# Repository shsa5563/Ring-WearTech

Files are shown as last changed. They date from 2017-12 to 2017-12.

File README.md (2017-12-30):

# Ring-WearTech
A research project on wearable technology

Requirements to implement this project:

    Hardware: 
    1. EFR32BG13 - starter kit, BMA280, Android Phone.
    
    Software 
    1. Simplicity Studio 4, Android Studio
    
    Steps: 
    1. Import the Firmware from this project to the Simplicity Studio 4
    2. Connect EFR32BG13 through USB and start Debugging/Execute
    3. Use two different instances of the Android Studio and import BLE and DTW apps, and execute them 
       (With new version you dont have to generate any signed apks)
    4. Open the DTW app and the BLE app. 
    5. The BLE advertisements will be visible in the BLE app, select it.
    6. Double tap on the sensor (BMA280) - the acknowledgment of the double tap is displayed on the BLE app.
    7. The user can start the gestures/commands/notes and it will be automatically transferred to the DTW app. 
    8. The DTW app provides visual graphs of realtime-data received, 
       to train with a particular command/notes/gesture - switch the button to the traning mode and hold-down the touch. and relese the touch once you are done with the gesture. 
    9. To recognise the gesture/command/notes, switch the button to the recognition mode and hold-down the touch to record the gesture and release once done. 
    10. If it is a match, it will be displayed on the app.
   
If eager to build the entire project ground up, 

    1. The schematics and the Layout desins are given in the "Altium-Schematics_Layout" folder.
    2. The components to order are given in the Excel sheet in same folder. 
    3. Run a free DFM check, and Submit the Gerber files to PCBWay 

The workinng prototype is uploaded on youtube,

   1. Ring-WearTech: https://www.youtube.com/watch?v=jb6WAhV-7PE
   2. BLE MESH: https://www.youtube.com/watch?v=EVaqNhNOGpU

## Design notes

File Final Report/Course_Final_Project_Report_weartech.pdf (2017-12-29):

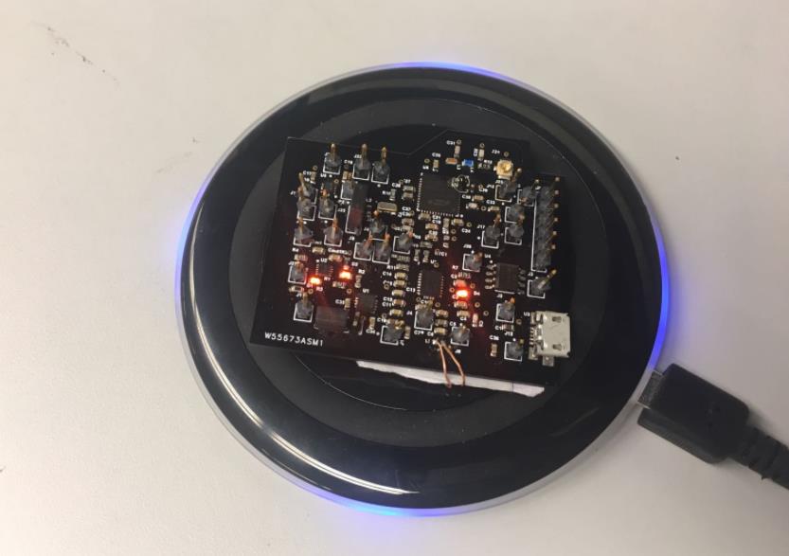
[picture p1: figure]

WearTech Project Report

LOW POWER EMBEDDED DESIGN
FINAL PROJECT REPORT

Team Name: WearTech

Team Mates:

Sanjana Kalyanappagol | Shekhar Satyanarayana
saka2821@colorado.edu | shsa5563@colorado.edu

Overview of the Project
A wearable ring/cap which is used to take short notes and control other devices through the movements of the user. The data is further sent to the application and trained using a Machine learning algorithm. The movements of the user are monitored using an accelerometer and it is also controlled using the tap sense of the accelerometer. The device is a prototype of a smart wearable technology which also obtains the ambient temperature and relays it to the application to display the ambient temperature.

What is the problem that this project is attempting to solve? How is this project going to solve this problem?

A wearable ring/cap which is used to take short notes and control other devices through the movements defined in the Mobile App.
With the advent of technology, it is bane to open your mobile/laptop/book to take a note of something important that strikes you all of a sudden or take a phone number of someone you meet unexpectedly. Say you are in a harsh environment, what if you had a wearable device with you all the time as a look-out for such situations.
In the Corporate world, say you are in a meeting and you need to take notes, rather than using notes/pens and disturbing others you can easily take notes of all the important points you need. Say in an unanticipated meeting, wouldn't you feel more secure, safe and confident with our device always at help.
In the field of Software Development & maintenance, one can face a lot of issues/bugs to be fixed within due dates. And with that constantly in mind, Most of us get solutions to the same when we are involved in our day-to-day activities such as driving, eating, talking with a friend, etc. Hence we would end up looking for a pen & paper, if not we would waste time memorizing the solution we had just found unless we have this device around which can keep a record of every thought that you want to be saved at any point of time.
Now with the buzz of IoT we have seen a lot of devices which could communicate with our home appliances. We provide a solution with the new Bluetooth Mesh Network to control other home appliances in addition to the Ring/Cap a single device which acts as a note taker.

The end-applications to such a device is enormous, it can be used to define the movement of a wheelchair, or used by old people/patients to communicate.

Use case described

Use Case Model to charge energy storage device:

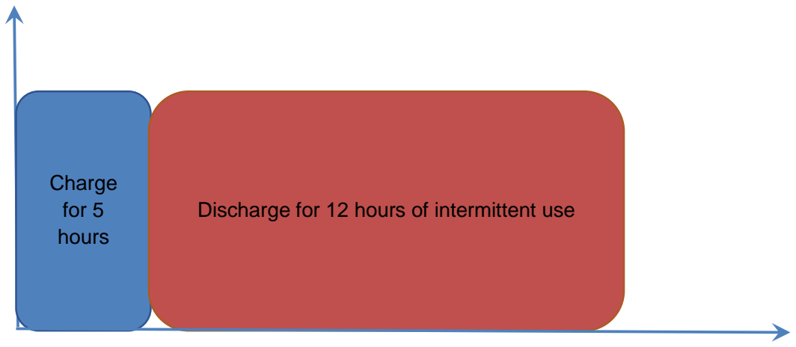
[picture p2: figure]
Charge for 5 hours

5hrs | 12hrs | Time -> (hrs)

Stage 1: The battery is of .2C standard charge capacity, thus to charge fully it will take 5 hours

Stage 2: As per our use case, we need the device to be usable for at the most 12hrs.

Discharge for 12 hours of intermittent use

Hardware functional block diagram

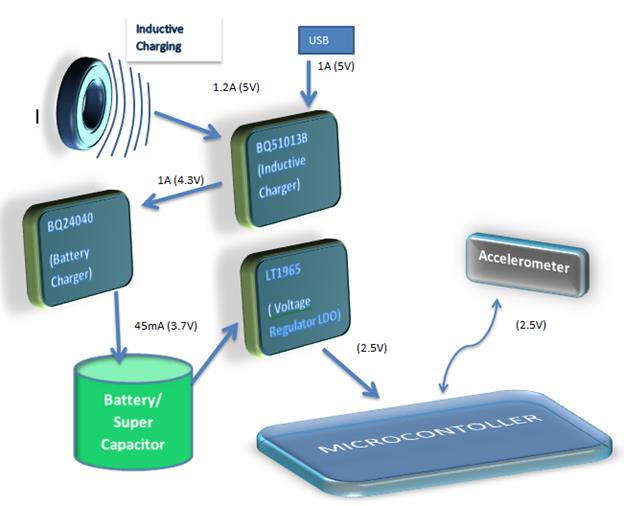
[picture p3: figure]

Key hardware components used

Battery | GMB401215-45mAh
PMU IC | LT1965
Processor | EFR32BG13– f1024
Inductive Charging IC | BQ5103B
Battery Charger IC | BQ24040
Sensor | BMA280 - Accelerometer
Sensor | BMA280 - Tap Sense
Sensor | BMA280 – Temperature Sensor
Switch | TPS1120DR

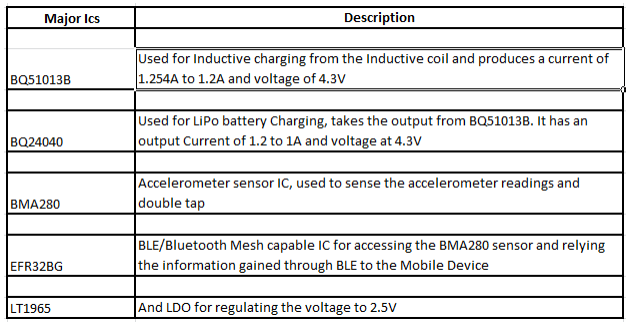
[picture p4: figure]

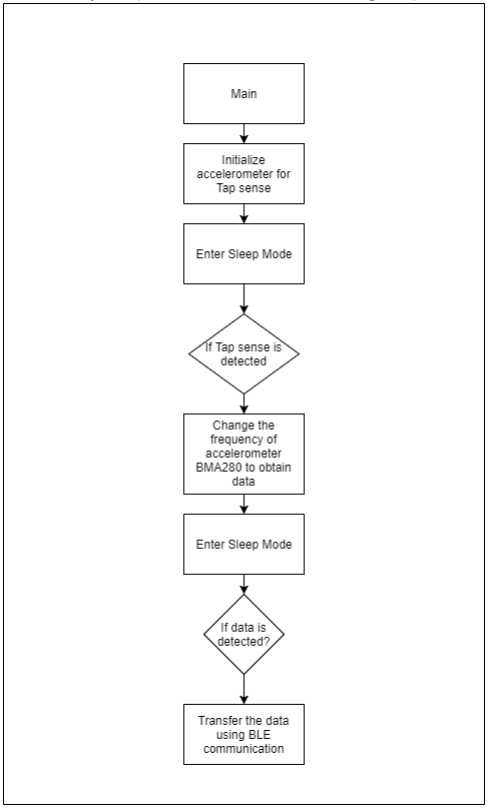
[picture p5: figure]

Functional Description (Software functional block diagram )

So how to use the Device ?
1. Charge the Device through Inductive or USB charging

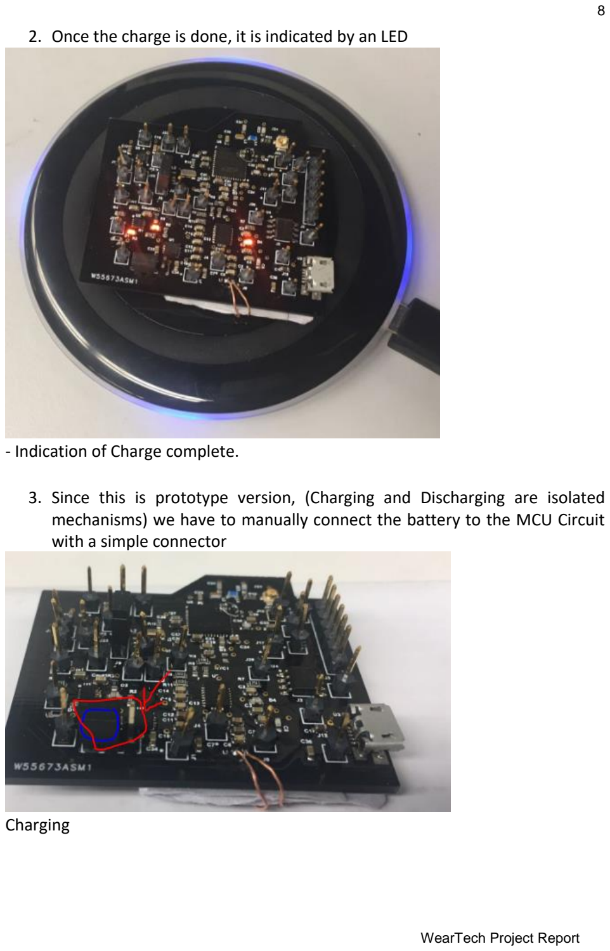
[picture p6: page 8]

2. Once the charge is done, it is indicated by an LED
- Indication of Charge complete.
3. Since this is prototype version, (Charging and Discharging are isolated mechanisms) we have to manually connect the battery to the MCU Circuit with a simple connector

Charging

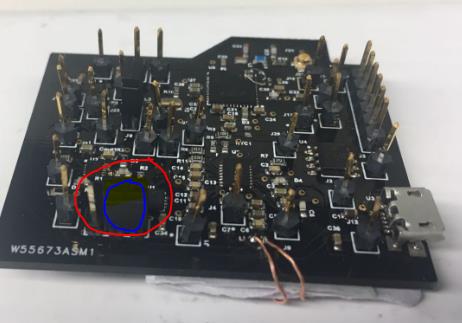
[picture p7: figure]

Discharging
4. Now the user can go ahead and start using the device,
a. A double tap on the device starts the Character recognition
b. Since this is a connection oriented BLE, you have to open the App and connect to it, and once the characters are recognised the BLE app seamlessly stars the Machine Learning App which can further start the recognition
c. The user can train any character by switching the “Training” button and for Recognition, toggle the switch to “Recognition”. If the Character Matches, it will display “A Match” - if not it will not. Since this is a prototype version, the user is provided with the information about the X,Y,Z distances, if distance of any of these two axes is <0.1 means that it recognised the character. This App for now is only tested for a single plane of the character written in air.
5. After the required functionality is completed the User can switch off the character recognition by “Double Tapping” again.

-The BLE MESH:
BLE MESH had to be integrated with the BLE, but the current sdks provided by the Silicon Labs are not compatible with this. Thus we implemented a simple BLE Mesh example. In our project we have used 3 MESH boards, one of them is the switch and the others have an LED attached to it.
1. To Use the BLE MESH, User has to have the MESH App.
2. Click on the Provision , scan and click on the devices scanned. Wait untill it goes green

3. Select the Settings option in each of the devices and connect it to a MESH group with appropriate options user wants.
4. Now the user can control the LEDs from the MESH app and even from the Board configured as a switch.

List of commands:

BMA280 Configuration Commands:
BMA280_RegisterRead(USART_TypeDef *usart, uint8_t address) BMA280_RegisterWrite(USART_TypeDef *usart, uint8_t address, uint8_t data)

BLE :

/* Create the temperature measurement characteristic in htmTempBuffer and store its length */
length = htmProcMsg(htmTempBuffer);

/* Send indication of the temperature in htmTempBuffer to all "listening" clients. * This enables the Health Thermometer in the Blue Gecko app to display the temperature.
* 0xFF as connection ID will send indications to all connections. */

gecko_cmd_gatt_server_send_characteristic_notification( htmClientConnection, gattdb_temp_measurement, length, htmTempBuffer);

Android App:

1. BLE APP
/*To Send the values of the Accelerometer from BLE APP to the Machine Learning APP*/

Intent sendIntent = new Intent();
sendIntent.setAction(Intent.ACTION_SEND);
sendIntent.putExtra(Intent.EXTRA_TEXT, | temperatureReading.getX() | + | "," | +
temperatureReading.getY() + "," + temperatureReading.getZ());
//Toast.makeText(HealthThermometerActivityFragment.this.getActivity() | , | "D(X:" | +
String.valueOf(Math.abs(temperatureReading.getX())) | + | ", | Y:"
+ | String.valueOf(Math.abs(temperatureReading.getY())) | + | ", | Z:"
+ | String.valueOf(Math.abs(temperatureReading.getZ()))+":)", Toast.LENGTH_LONG).show();
//Toast | td | = | Toast.makeText(HealthThermometerActivityFragment.this.getActivity() | ,
"D(X:" , Toast.LENGTH_LONG);

sendIntent.addFlags(Intent.FLAG_ACTIVITY_REORDER_TO_FRONT); sendIntent.setType("text/plain");

startActivity(sendIntent); refreshUi();

2. Machine Learning Algorithm (Dynamic Time Warpping):
final DTW | lDTW | = new DTW();
// Iterate the Histories.
for(int i = 0; i < 3; i++) {
// Fetch the Primitive Histories for this Axis.
final | float[] | lTraining | =
MainActivity.primitive(MainActivity.this.getTrainingHistory()[i]);
final | float[] | lRecognition | =
MainActivity.primitive(MainActivity.this.getRecognitionHistory()[i]);
// Calculate the distance using Dynamic Time Warping.
lAverages[i] = lDTW.compute(lRecognition, lTraining).getDistance();

What aspects of the project are considered high risk? How is this risk planned to be mitigated?

Risk factors:

1. We might end up consuming more current because we are using accelerometer (BMA280) to both turn on the entire device and for data acquisition.
2. Our project involves inductive charging for the battery which is a new concept for us and we are not sure if we will be able to get the appropriate energy requirements from inductive charging as required by our application.
3. The issue with accelerometer data acquisition is that we might not know how much data is enough /less to compute the algorithm on the data and detect the pattern or the command
4. The Machine learning algorithms always need more information about the data to differentiate different patterns accurately. And for such high data handling it needs more high powered CPUs, which would help in computing the algorithms on the data in few milliseconds
5. The main problem is the time it takes to capture the data and send the data to either Phone/Cloud => process the data through FTT/any other algorithms to make sense out of the data and pass it through the pattern detector and predict a most accurate command. - All these have to happen within few miliseconds, if not the product can fail

6. The Bluetooth mesh network is a new technology which needs a lot of time to understand and troubleshoot the issue faced.

Mitigation:
1. We are currently using accelerometer (BMA280) in low power 2 mode with 0.5 ms of sleep duration. So, we can consider reducing the current consumption either by increasing the sleep duration or using the accelerometer in a mode with lesser current than low power 2 mode.
2. We will focus on referring more documents and articles on inductive charging to get the required energy requirements. If we are beyond the schedule and still not successful with inductive charging, then we will consider switching to an alternative power source such as USB charging.
3. To know how much data is enough/ less from the accelerometer, we have found out a simple solution to configure a simple app from the mobile (all mobiles have a accelerometer and a gyroscope).
We take the values of the mobile-accelerometer through a simple javascript application, populate the data to a csv-file/ populate the data in realtime to the algorithm we are generating. Thus before the firmware development we will have a clear idea on how much data would be required for acquisition.
4. We are trying to get a simpler lightweight Machine learning algorithm - which can run on a smartphone. If we cannot find the exact configuration we need, we will try dumping the data to any cloud platform to do the work for us -say AWS/IBM Watson etc..
5. Since it is considered as a prototype, even with a max delay to recognise the commands, the minimal success would be to achieve a command. Thus if the commands are recognised we can go ahead and start mitigating the delay.
6. We will focus on configuring only 1 or 2 devices with Bluetooth mesh network to make a simple network by referring documentations and receiving guidance from people who have worked on Bluetooth mesh network. If we are unable to achieve Bluetooth mesh network in the required time then we will consider using ZigBee/WiFi.

Energy use mode model

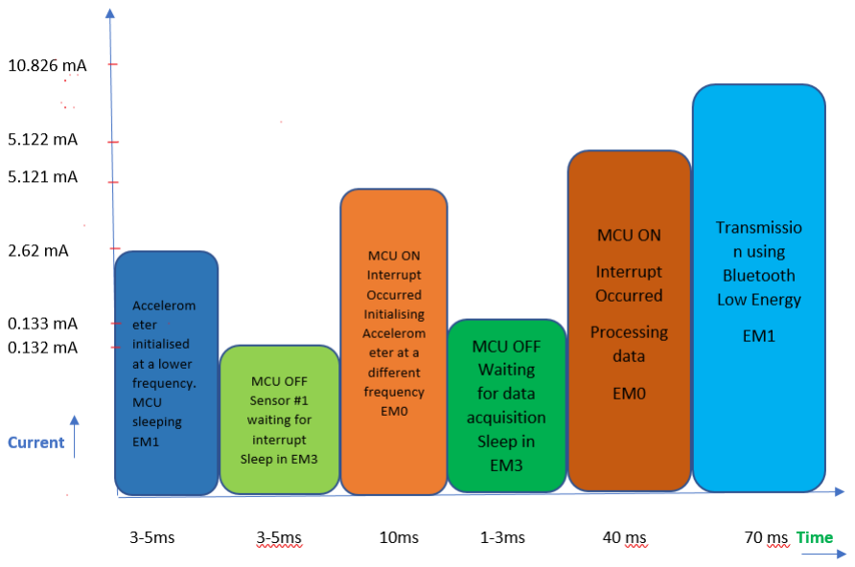
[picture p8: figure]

Stage 1:
Configuring the Accelerometer for double tap sense (3-5ms)
State 2:
MCU is off, Sensor #1 i.e Accelerometer tap sense is On and it is waiting for an interrupt to switch on the entire device. The device stays in this state for about 3-5 ms after the user has used touch sense to switch on the device. It uses SPI serial port interface which works in EM3 for Blue Gecko and also, we wait for an interrupt in EM3 energy mode.
State 3: MCU becomes on when an interrupt occurs, hence it will be in EM0 mode. In the interrupt service routine (Accelerometer data acquisition) is switched on. This state will take about 10 ms to handle the interrupt and configure the Accelerometer to accept the Data acquisition at higher frequency.
State 4:
In this state, MCU is off while Accelerometer is waiting for an interrupt i.e it is waiting to receive data from the user. As use case considered is when user switches on the device and immediately writes the data, this state will approximately take 1-3 ms.
State 5:
In this state, MCU becomes on when an interrupt occurs i.e when data is received from the user and the data is processed. This state will approximately take 40 ms to handle the interrupt and process the data.
State 6:
In this state, the data is transmitted to the mobile phone using BLE and it is interpreted to display the character received. This will take about 70 ms and operates in EM1 for transmission.

Calculations to specify the Energy Storage Device
- Average current / energy capacity calculation

Determining the average weighted power out of battery using Blue Gecko:

On duty cycle:
Assuming that the blue gecko is given a input voltage of ~2.5v and ~1.9v is an output voltage.
Blue Gecko’s efficiency at ~2.5v input to ~1.9v out is 2.5v/1.9v = 75.75%
Since it cannot be a 75.75% ,
Weighted average power out of battery = (On duty cycle * On time current * 2.5v) / 75.75% = (0.2 * 10.826mA * 2.5v) / 75.75%
Weighted average power out of battery = 71.70 uW

Off duty cycle:
Blue Gecko efficiency at ~3.3 input to ~2.5v out is 2.5v/3.3v = 75.75%
Weighted average power out of battery = (Off duty cycle * Off time current* 2.5v) / 75.75% = (98.8 * 0.133mA * 2.5v) / 75.75%
Weighted average power out of battery = 433.68 uW

Total average power out = Weighted on duty cycle average power + Weighted off duty cycle average power
= 71.70 uW + 433.68 uW
= 505.38uW

Average energy the battery must provide on the use case: = 12 hrs of use * 60 mins * 60 secs * 505.38uW
= 21.83J

Peak currents and Peak current step functions that will need to be considered

BQ51013B has an inductive charging: the max current from the coil can be 1A USB : the max current from the USB is 1A

The MAX current the BQ24040 (Battery Charger) & BQ51013B (Inductive charging) can handle is 1.245A

The Energy Harvester input doesn’t require any current limiting circuit.

Engineering reasons why the particular Energy Storage Device has been selected
- Number of recharge cycles
- Provide supporting documentation that the use case number of recharge cycles can be achieved.

As per our calculation, we need a battery with the following specifications: Average energy 21.83J
Vout from the Battery is ≈ 3.3v
Max current required 10.826mA (all on - MCU, Sensors, BLE)
If the product is targeted to be used for 1.5years , 5 days a week. We have 390 recharge cycles.
With weighted average power = (0.2% *10.826mA) + (99.8% * 0.133mA) = 15.439mA
15.439mA * 12 (->12 hours) = 1.83mAh
For rechargeable cells the battery nominal capacity should be 10x capacity.
Thus total =>18.3mAh

We need a battery with 18.3mAh and 21.83J
Thus | selected: | https://www.powerstream.com/lip/GMB401215
45mAh_With%20PCM_A0.pdf (https://www.powerstream.com/lip/GMB401215%20%2045mAh_With%20PCM_A0.pdf)

Above calculations substantiates the choice of the Energy source to be Battery and not Super-Capacitor.
Batteries provide consistent voltage (3.7 V) - which is within the voltage range of the components we are using in our application. Since our application does not require any bursts of current and we need our device to discharge the power for a long time - we choose Battery.

Why is the particular MCU / SoC / Radio being proposed?

EFR32BG13 is chosen since it has the supported sdk for Bluetooth Mesh

Why is the particular PMU solution being proposed?

We researched for Inductive Charging, BQ51013B is the best available TI IC for inductive charging which also supports alternative USB charge mechanism. BQ24040 is required to charge the LiPo battery from the BQ51013B.
LT1965 is chosen to regulate the voltage at 2.5V, which is provided to the MCU.

Supporting documentation that voltage droops due to possible current delta functions of this low energy mode device have been engineered not to result in a failure
a.At Vin = min
Yes, the voltage was increased of about 0.1mV. The Supply Voltage was about
3.28V | to | the | PMU | IC | from | the | battery.
The PMU IC would be giving approximately 2.5V output.

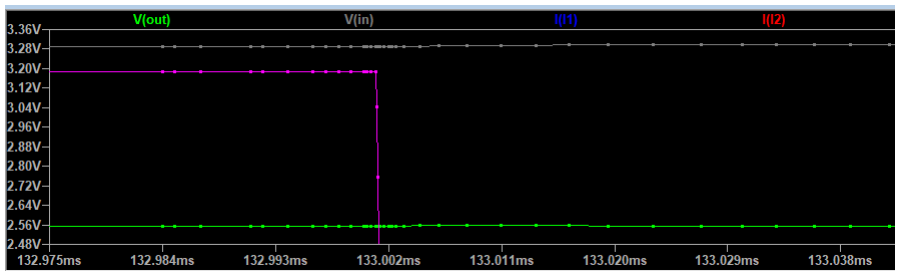
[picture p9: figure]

Note: The silver line indicates the stabilized voltage change

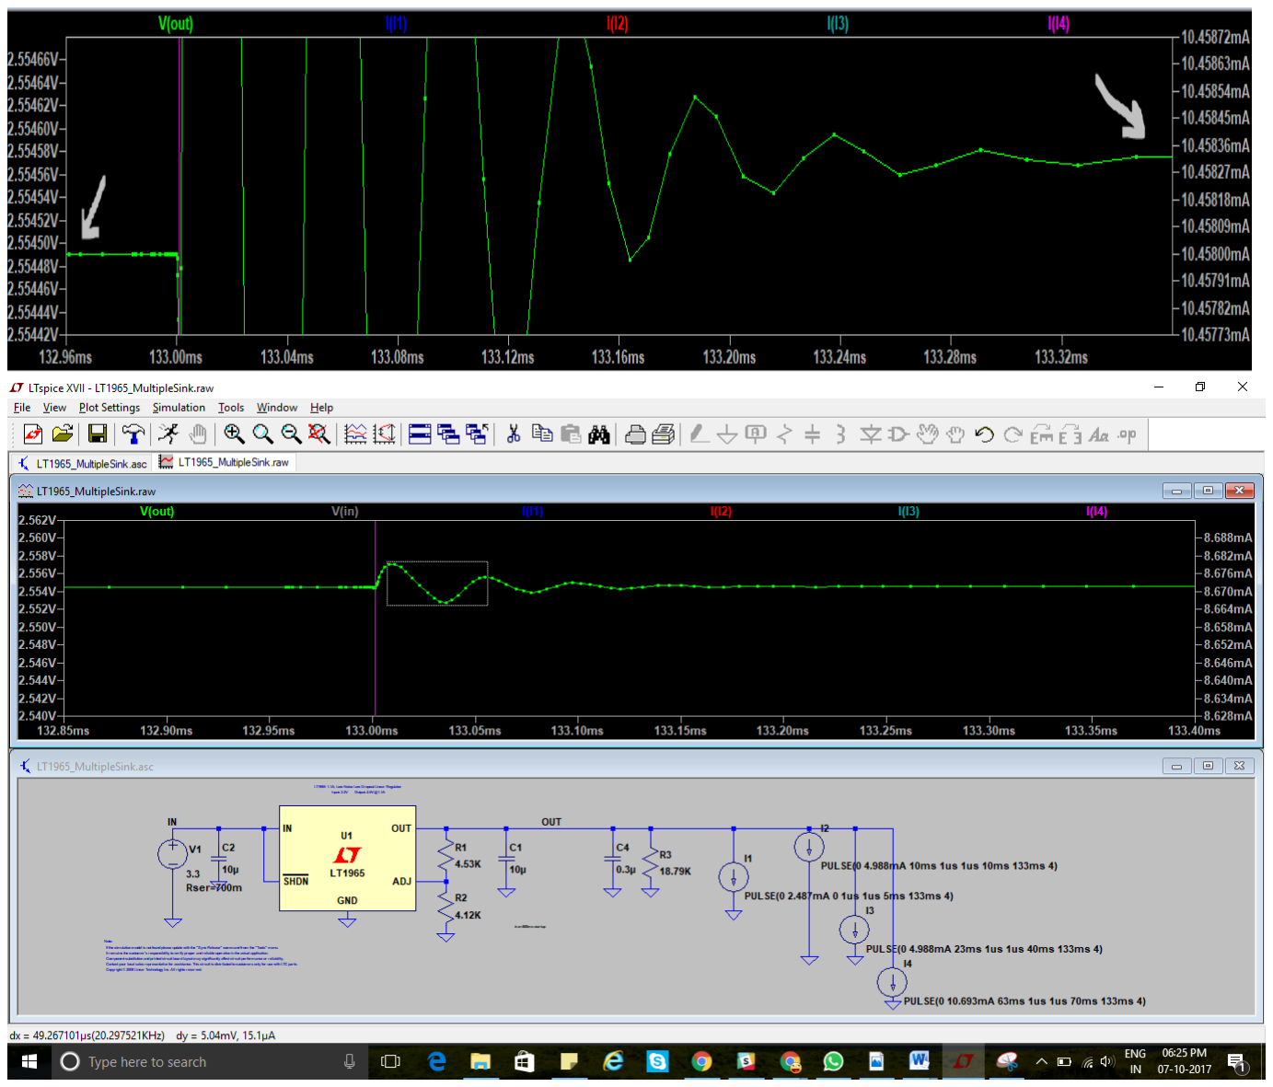
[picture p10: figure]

5mV is the ripple which is within the specifications of 0.5Vp-p

When the dynamic load is added there is a dip in the voltage, the min value is 2.553V, the appropriate voltage supplied by the battery is 3.296V
The Stabilized output voltage of the battery before the dynamic load was 2.5544V Thus, there is a variation of 2.5544-2.553 = 0.0014V => 1.4mV which is within the specifications.

Dynamic current step up load:
Yes, there was a voltage dip with dynamic step up load.

Below screenshot shows the voltage dip when there is dynamic current step up load i.e when the load switches from EM0- Accelerometer interrupt to EM1-BLE transmission.

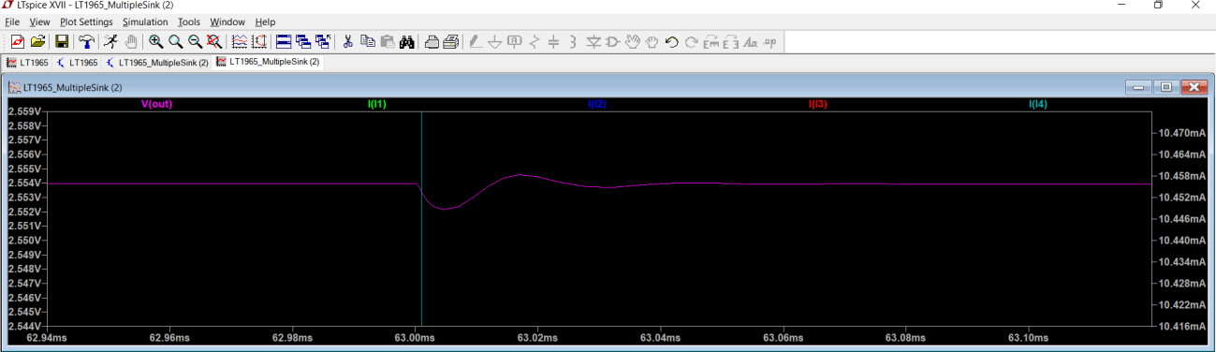
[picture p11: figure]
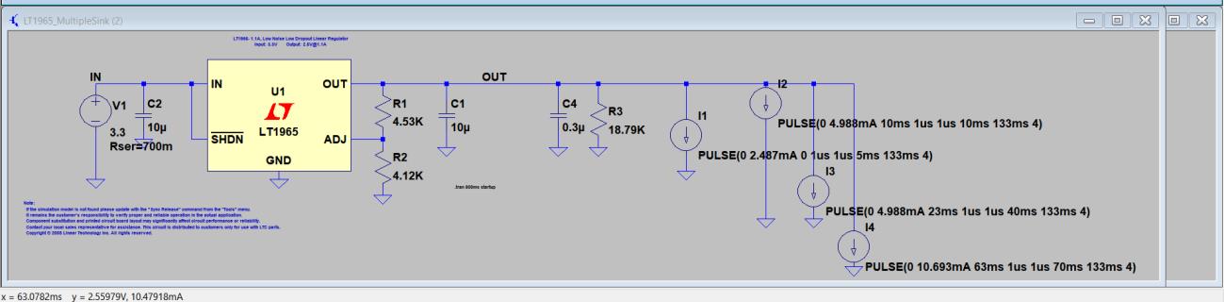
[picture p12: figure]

Minimum out voltage is 2.552167 V Therefore, voltage droop = 1.83 mV < 0.5Vp-p
Hence, this is within the IC specifications

The stabilized voltage in EM0 before dynamic step up load = 2.55399 V The stabilized voltage in EM1 after dynamic step up load = 2.55394 V

b. At Vin = max i.e Vin = 4.2 V

Dynamic current step up function load:

Yes, there was a voltage dip with dynamic step up load.

Below screenshot shows the voltage dip when there is dynamic current step up load i.ewhen the load switches from EM0- Accelerometer interrupt to EM1-BLE transmission.

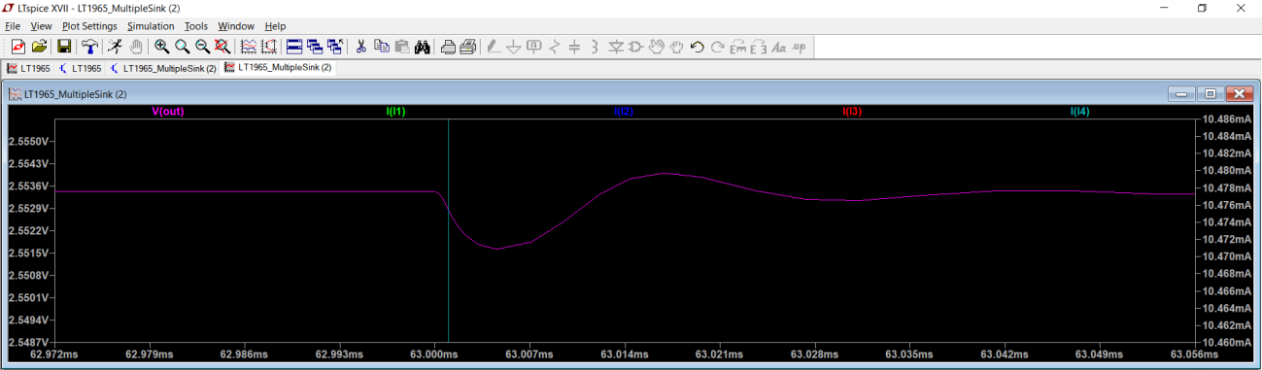
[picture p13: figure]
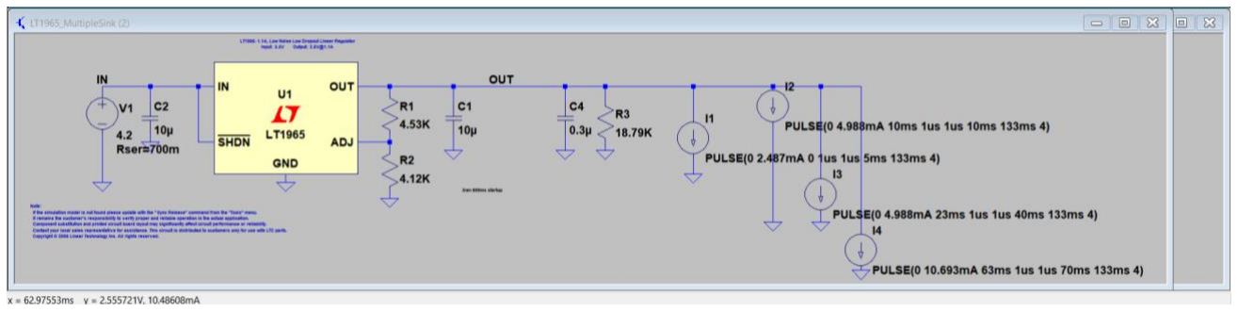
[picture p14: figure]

Minimum out voltage is 2.5516 V Therefore, voltage droop = 1.8 mV < 0.5Vp-p
Hence, this is within the IC specifications

The stabilized voltage in EM0 before dynamic step up load = 2.5534 V The stabilized voltage in EM1 after dynamic step up load = 2.5533 V

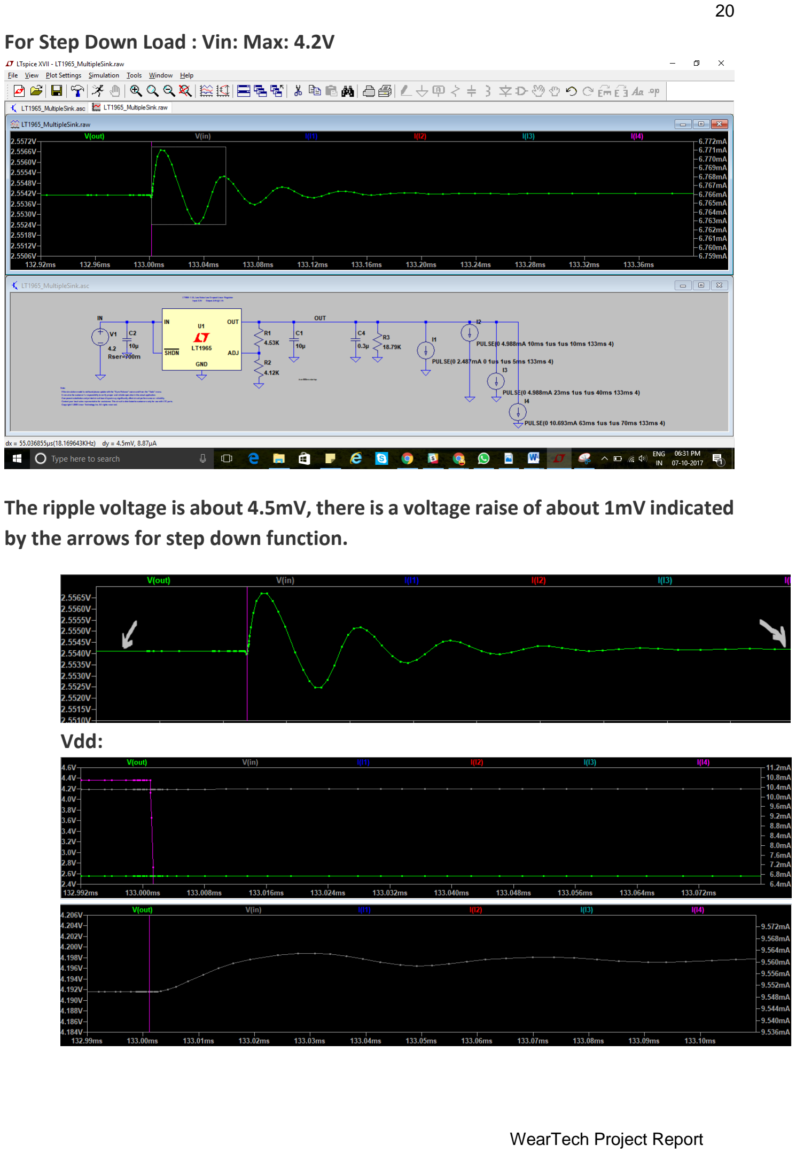
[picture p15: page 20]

For Step Down Load : Vin: Max: 4.2V

The ripple voltage is about 4.5mV, there is a voltage raise of about 1mV indicated by the arrows for step down function.

Vdd:

The Vdd was increased to about 5mV to 4.198v

When the dynamic load is added, a voltage dropped to about 2.5522V, the stabilised voltage before the variation was 2.55407V

The difference of about 1.87 mV
Which is within the specifications of 0.5Vp-p ripple.

Simulation for with & without Dynamic load:

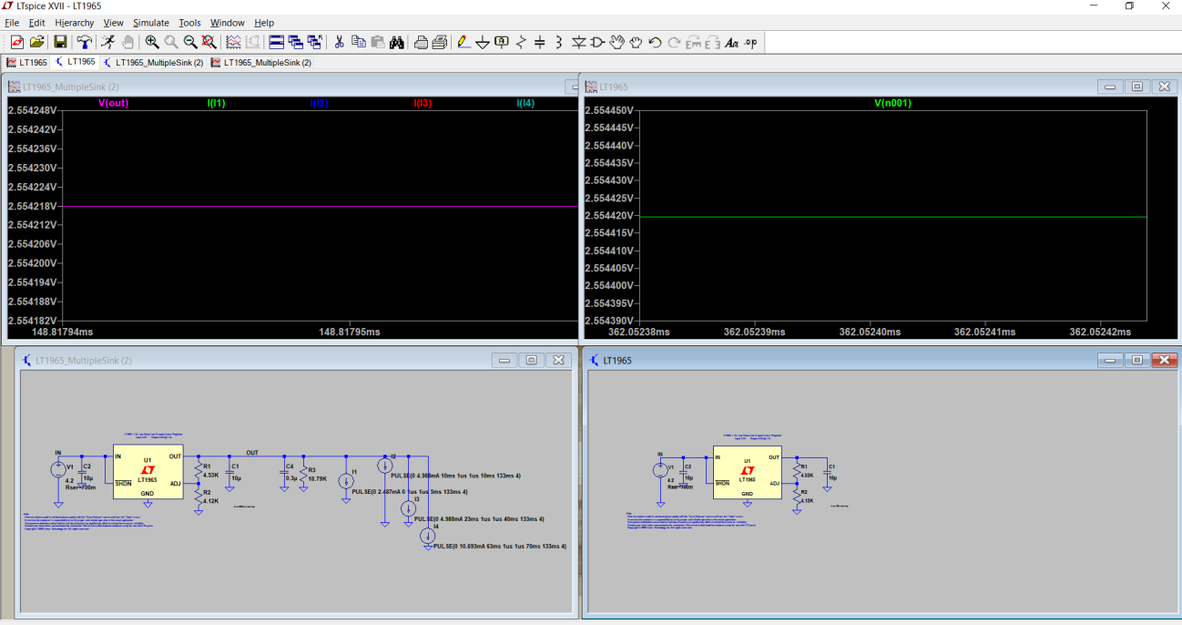
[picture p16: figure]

The circuits as shown above:

Voltage when there is no dynamic load: 2.5542 V (Image on the right)

Voltage when there is dynamic load: 2.5542 V (Image on the left)

Hence there is no change in the voltage when a dynamic load is added to the circuit.

The min voltage when the power supply is drooping is 2.53 V which is within the specifications of the IC.

Proper engineering selection of the required bulk or PMU ceramic load capacitance

The value of Decoupling Cap is calculated as the project’s circuit doesn’t require any Bulk load capacitance (Thus not taken into consideration)
Decoupling capacitors:

Blue Gecko: According to hardware considerations, we have considered a decoupling capacitor (ceramic capacitor) of value 0.1 uF Ref:https://www.silabs.com/documents/public/application-notes/an0002.1-efr32-efm32-series-1-hardware-design-considerations.pdf (https://www.silabs.com/documents/public/application-notes/an0002.1-efr32-efm32-series-1-hardware-design-considerations.pdf)

BMA280: We have considered a decoupling two capacitors of 100 nF( 0.1 Uf each). Ref:http://www.mouser.com/ds/2/783/BST-BMA280-DS000-11_published-786496.pdf (http://www.mouser.com/ds/2/783/BST-BMA280-DS000-11_published-786496.pdf)

Hence total capacitance = 0.3 uF

Thus, the capacitance for the power plane is the same value as the decoupling capacitor of 0.3uF.

According | to | the | Data | sheet | of | LT1965:

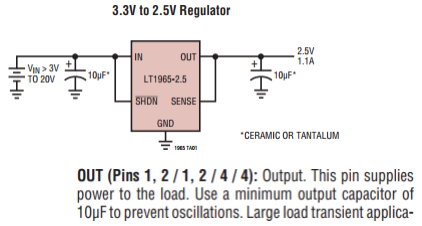
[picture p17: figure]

And also ceramic capacitor of type X5R is preferred according to the data sheet of PMU and for the decoupling capacitors for MCU and accelerometer sensor. Ref:https://www.silabs.com/documents/public/application-notes/an0002.1-efr32-efm32-series-1-hardware-design-considerations.pdf (https://www.silabs.com/documents/public/application-notes/an0002.1-efr32-efm32-series-1-hardware-design-considerations.pdf) http://cds.linear.com/docs/en/datasheet/1965fb.pdf

Considering the DC-Bias characteristics, we have selected the below part-number for the load capacitor which would suffice with the condition given in the datasheet (min of 10uF for the load capacitor)

We have a decoupling capacitor of 0.3 uF. Considering the DC-Bias characteristics, we have selected the below part-number for the load capactior which would suffice the requirement.

We have a decoupling capacitor of 0.1 uF each at each volatage terminal of BMA280 and PMU.

Selected part number to give a capacitance of 0.1UF at 2.5V which is our working voltage is :
http://psearch.en.murata.com/capacitor/product/GRM188R71C104KA01%23.ht ml (http://psearch.en.murata.com/capacitor/product/GRM188R71C104KA01%23.html)
Ref: http://cds.linear.com/docs/en/datasheet/1965fb.pdf

ESD protection has been engineered on these user accessible lines to ensure a long-life product

A TVS DIODE 5VWM 12.5VC SC88 is selected for the power lines from the USB, the
inductive | charging | does | not | need | any | ESD | diodes.
Since the BMA 280 is on the board, we do not need any ESD diodes for the communication.

Planned Development Schedule:

Task | Date to be finished | Date it was finished | Status
MCU Selection | 9/16/2017 | 9/16/2017 | Done
Sensor Selection | 9/16/2017 | 9/16/2017 | Done
Battery Selection | 9/23/2017 | 9/23/2017 | Done
Radio Communication Selection | 9/23/2017 | 9/23/2017 | Done
PMU Selection | 9/23/2017 | 9/23/2017 | Done
Energy Charger Selection | 9/23/2017 | 9/23/2017 | Done
Current profiler | 9/30/2017 | 9/30/2017 | Done
Energy Spike Calculation | 9/30/2017 | 9/30/2017 | Done
Voltage Droop Simulation | 10/8/2017 | 10/8/2017 | Done
Schematics | 10/28/2017 | 11/4/2017 | Done
Foot print generation | 10/28/2017 | 11/4/2017 | Done
Layout | 11/4/2017 | 11/11/2017 | Done
Ordering parts and board | 11/11/2017 | 11/20/2017 | Done
Assembly of the board | 11/27/2017 | 12/1/2017 | Done
Testing of the board | 12/10/2017 | 12/12/2017 | Done
Firmware for tap sense | 12/12/2017 | 12/15/2017 | Done

Firmware for accelerometer data | 12/12/2017 | 12/15/2017 | Done
Firmware for temperature | 12/16/2017 | 12/16/2017 | Done
BLE code development | 12/14/2017 | 12/14/2017 | Done
Custom Application development | 11/15/2017 | 12/15/2017 | Done
Machine learning algorithm for data interpretation | 12/15/2017 | 12/15/2017 | Done
BLE mesh implementation | 12/16/2017 | 12/16/2107 | Done
Integration of the code | 12/15/2107 | 12/16/2017 | Done
Testing of firmware | 12/15/2017 | 12/16/2017 | Done

Verification plan :

To be verified | Definition of passing | Date test performed | Tested by | Measur ed result | Passed ?
Supply voltage to the MCU should be within the minimum and maximum specification | The voltage should be within 1.8V to 3.3 V | 2/12/17 | Sanjana | 2.5 V -Measur ed using multiet er | Passed
Supply voltage to the BMA280 sensor using SPI interface should be within the minimum and maximum specifications | The voltage should be within 1.2V to 3.6 V | 2/12/17 | Sanjana | 2.5 V -Measur ed using multiet er | Passed
Signal quality of SPI communication line | Check correct signal level transition on the oscilloscope | 14/12/17 | Sanjana | Signal level at 2.5 V -Measur ed using multiet er | Pased
Firmware Block of BMA280 using SPI interface: The | The interrupt should get triggered whenever the | 15/12/17 | Sanjana | Verifie d the signal transiti | Passed

MCU | is
receiving
correct data
from the sensor

sensor senses
data.
The | MCU | is
receiving | the
correct
accelerometer
reading from the
sensor- verify
clock too.
Verify | | Chip
Select of SPI
goes low while
transferring data

on on a
logic
analyse
r and
interru
pt
signal
was
also
verified
on the
IDE in
debug
mode

The radio is
transmitting
data correctly

Verify at the
receiver’s | end
the | data
received
14/12/17 | Shekhar | Tested with soc- smarph one exampl e code, to verify its connec tion and workin
g | on
| | BLE.

Passed

Supply voltage
from the USB

The voltage
should be within
4.3 to 5 V
3/12/17 | Shekhar | 5V obtaine d which

Passed

| | | | is within the limits
Supply current from the Inductive coil | 50mA to 1A | 11/12/2017 | Shekhar | 1A -Measur ed with ammete r in series | Passed
The Current out from the Inductive Charger – BQ51013B | 700mA to 1.2A | 11/12/2017 | Shekhar | 700-800 mA -Measur ed with ammete r in series | Passed
The Current input to the BQ24040 | 700mA to 1.245 A | 11/12/2017 | Shekhar | 800 mA -Measur ed with ammete r in series | Passed
The Voltage at the RECT pin | Must be within 4.3 to 5V | 10/12/2017 | Shekhar | 4.3V -Measur ed using multime ter | Passed
The voltage at the BAT | 3.5 to 4.2V | 10/12/2017 | Shekhar | 4.2 V -Measur ed with | Passed

Pin/VOUT from BQ24040 | | | | ammete r in series
The current at the BAT Pin/VOUT BQ24040 | 45mA +/- 10% | 11/12/2017 | Shekhar | 22 mA – 45 mA -Measur ed with ammete r in series | Passed
The voltage input to the LDO LT1965 | 1.8 to 20 V | 7/12/2017 | Sanjana | 3.7V -Measur ed with ammete r in series | Passed
The voltage output from the LDO to MCU | 2.5V exact | 7/12/2017 | Sanjana | 2.5V -Measur ed with ammete r in series | Passed

Difficulties encountered in the project:

One of the foremost difficulty encountered is that both of us, as a team had very little experience in hardware and this is the first class we have got an opportunity to learn and design a hardware of our choice. It took us a while to adapt to Altium software and get the best design for our board.

As we had proposed to work on BLE mesh, we had to make the right choice of the MCU board because most of the MCUs in Blue Gecko family support BLE mesh but all of them are yet to support the APIs for BLE mesh except EFR32BG13 boards. This information is not available on any of the silicon labs site and we had to confirm this only by contacting silicon labs and discussing with peers who have already worked on BLE mesh.

Implementation of Machine Learning algorithm for character interpretation is one of the difficulties encountered. We had to do a lot of study and research to choose an optimised algorithm that trains the data from the accelerometer and interprets the character accordingly. The machine algorithm is classified into classification and regression type of algorithm, While, choosing one of the algorithms and doing a research, we found out that regression type of algorithm is better in real time for alphabet recognition. Support Vector Machine(SVM) is a widely used regression type of algorithm, but the problem with SVM is that, it uses huge amount of data sets, and dataset is not common i.e the dataset is not same for different accelerometers. Each device has a different dataset and it consumes huge amount of time. Hence an alternative to SVM algorithm is Dynamic time warping algorithm. In this algorithm, it calculates the Euclidian’s distance and generates matrix depending on X, Y, Z axis array values. Since this calculation is done in real time, the training and recognition of any devices in real-time is accomplished without any predefined dataset.

In our project, we are obtaining data using the accelerometer and train the dataset accordingly. We faced a difficulty while reading the required data from the accelerometer because BMA280 does not provide us the resolution required to train the dataset accurately. We tried giving a resolution of 2g and a maximum frequency(2Khz) but it still failed to provide us the accurate data. So even the maximum frequency was less for our application.

Unable to send an array of values to BLE: As maximum payload for BLE is 20 (length) we were unable to send an array of values to BLE application hence we had limit by sending each acceleration data of X,Y,Z axis and the train the it accordingly.

One of the other difficulties we faced is while developing the firmware block for BMA280. Firstly, it took a lot of time to figure out that the dev kit is not getting detected because of the version of SDK we had downloaded. The simplicity studio 4 which we had downloaded did not have BLE 2.6 SDK and hence it was not supporting the kit. Later on, after developing the firmware block on the example code, it gave a lot of linker errors and which consumed lot of time to be solved. This process was not as easy as using leopard gecko with simplicity studio 3, hence setup was one of the difficulty.
LCD interfering in BMA280(SPI) communication: The LCD functionality was causing a problem in working of BMA280. The RXDouble register that we were reading while doing a register read from BMA280 always gave a 0XFF instead of reading an appropriate value. After commenting LCD functionality, we were able to read appropriate values hence we were able to read correct interrupt status to differentiate between single tap, double tap and accelerometer reading. Even while integrating with BLE, we faced the same problem, after realising that the BLE code was causing a problem, we put a register read after every command to find the solution of the problem. We realised that in the init() function, there is a hardware init() function that has commands for LCD support, after commenting that, we got our BMA280 working appropriately with BLE.

Difficulties faced with HFXO oscillator: We had a mistake in schematics of the HFXO oscillator because of which our code was not running properly. Even while testing the BMA280 accelerometer code, though we did not require HFXO for its functionality, the code was getting stuck in a while loop, waiting for readybit of HFXO to be set in one of its init() functions and if we commented that, then the an error use to pop up displaying the error caused due to power loss and same repeated. So until we fixed the HFXO connection, we could not check any of our code on the board.

BLE & Bluetooth mesh together: Initially we had proposed a method which integrated BLE and BLE mesh together in an application. But with time, we realised that they cannot be made to work together, both BLE and BLE mesh have their own events and characteristics which cannot be integrated.

Battery and coil reorder: We intended to use a lipo battery of 45mAh rating and the one we needed was available only on of the websites which needed us to wait for their quote to order the component. Hence it delayed ordering of our battery but instead we had to order another battery from sparkfun with differ specifications to support our application and same applies to the coil. Hence this put us at risk until we tested the components on our board.

Breakpoint in BLE: If we keep a break Point in the BLE advertisement or GATT service char send, the BLE application does not work because it disconnects the device from the application while doing a step by step debugging. Hence it is very hard to understand what actually happens while doing a BLE communication and tweak in our code into already available example code.

Resistor Issues: According to the Use case model, the Battery capacity should be 45mAH. But during the component-order state, the part was not in stock. Thus the ISET resistors value in the Battery Charger circuit (BQ24040) had to be changed. According to the Circuit we had ordered 4k Ohms resistor which should be providing a 45mA of charge current to the Battery. Since we could not find a 45mAH battery – we ordered a 40mAH and 110mAH from sparkfun. The issue was that the standard Charger Current of both the 40mAH and 110mAH is 0.2C, a max of 22mA is the standard charge current. But the resistors were offering a 45mA of current. So, we had to change the resistor to 12K.

Battery Datasheet Issue: The Battery datasheet for the battery was not available in the Sparkfun website as well, we even called them but in-vain. We needed the data sheet to get the information about the Standard Charge and Discharge Current. Once we got the battery we saw the specs on the Battery and we looked for any datasheet with that part-number. We got one from Alibaba.com from which we calculated the ISET resistors.

The Application diagram provided in the Inductive Charging was improper. The capacitor values were wrong and the Part numbers specified in the DataSheet for the P-to-P channel switch was not present. We had to approach peers who have worked on Inductive Charging to make sense out of the Application Diagram.

Thermal pads in BQ51013B: The BQ51013B had a thermal pad footprint which had smallest distance between the pad and thermal pad. This difference could not be solved, and even the DFM check gave an error. Thus we had to change the thermal pad of polygon shape. The extended thermal pad was changed as extra pads on the IC.

Android SDK Issue: The BLE app and the Machine learning app were developed separately. Both the applications were of different SDK, and this should not be an issue to merge the APPs but the problem was never known. Could not merge both the applications due to the SDK issues. The solution to this was to get the Machine Learning App from BLE app whenever we receive any information about the change in accelerometer. This was achieved by Intent Messages.

Intent Messaging in Android always starts the second App as a new instance, due to which whenever we got new data from the BLE app, it used to create a new instance of the Machine Learning APP. The issue with this is that the Machine Learning algorithm was not saving all the values. To overcome this I used a flag and a change in the Manifest file to set only a single instance of the APP.

Faced difficulty in measuring Discharging/Charging of Battery (in the units of Current/Voltage). Found out how to discharge/charge battery and supercap.

Hardware Issues:

HFXO Crystal:
Root cause of the hardware issue:
The schematic connection to the HFXO oscillator was wrong. The oscillator we have generally used in the past is two pin oscillator and this was the first time we used a 4 pin crystal. We ended up interchanging a connection to hot with a connection to ground, because of which we could not run any code with HFXO Enabled on our MCU.

Solution to Hardware issue:
After a wide range of proposed-fixes for this solution, the pad of the footprint of the Crystal came out due to overheating the board. And this is when the solution for a DeadBug was introduced. For one of our boards we had to solder wires from the MCU pins but the other board was intact. The basic Idea behind the solution is this: To remove the crystal from the board, placed it on top of the MCU using hot glue and made wired connections to the correct pads. Etch and remove the wrong trace, and connect the appropriate pins of the MCU to the Crystal. One more information we found out was that we don't have to connect the Sensor pin and the Ground Pins, since we were not using any temperature sensor for the Crystal. This made it easier to apply the above mentioned solution.
This way we fixed this issue and we were able to test our BMA280 code and BLE code on our board.

ESD Diode:

Root cause of the hardware issue:
Choice of the ESD diodes were incorrect. Even though the clamping voltage was enough. There were some reasons that they were conducting below the clamping voltage.

Solution to Hardware issue:
We removed the ESD diode from our design. Tested our design without the ESD diode and only when we were assured, this would not cause any more problems, we moved forward to the next step.

Battery and Resistor for the Battery circuit:
Root cause of the hardware issue:
According to the Use case model, the Battery capacity should be 45mAH. But during the component-order state, the part was not in stock. Thus the ISET resistors value in the Battery Charger circuit (BQ24040) had to be changed. According to the Circuit we had ordered 4k Ohms resistor which should be providing a 45mA of charge current to the Battery. Since we could not find a 45mAH battery – we ordered a 40mAH and 110mAH from sparkfun. The issue was that the standard Charger Current of both the 40mAH and 110mAH is 0.2C, a max of 22mA is the standard charge current. But the resistors were offering a 45mA of current.

Solution to Hardware issue:
Hence, we had to change the resistor to 12K which provided us a lesser required current.

Lack of LEDs and extra sockets on unused GPIO pins in the MCU circuit for BMA80: Root cause of the hardware issue:
When we are trying to test double tap and single tap interrupt in normal run mode, it is hard to identify if the interrupt is triggered unlike in debug mode we can put a breakpoint and read the register and confirm the interrupt status. As the accelerometer is not sensitive, the double tap has to be tapped in a specific way for it to be triggered. Hence it was hard to confirm if there was a double tap because of no LEDs or extra sockets in the MCU design to confirm the interrupt by making these GPIO pins high.

Solution to Hardware issue:
We solved this issue using software by passing a string, indicating , double tap to the BLE application to let us know that there was a double tap interrupt.

Lack of LEDs to test BLE Mesh:
Root cause of the hardware issue:
As above we did not have a LED to test BLE mesh on our board nor sockets for the GPIO pins

Solution to Hardware issue:
We connected an external LED to the GPIO pin socket of BMA280 power pin for which we are doing load power management. First, we connected it with a 1k resistor but the LED was not glowing. Then we realised as our voltage is only 2.5V, we removed the resistor and it provided enough current for the LED to glow and hence we could test the mesh application on our board.

BMA280 Sensor Issue:
Root cause of the hardware issue:
Since our goal was to gain the smallest wearable device, we searched for sensors with integrated functionalities. But the issue is that even though it is equipped with multiple functionalities it is not effective. To recognise a character in the Machine Learning, we need a lot of data points, with the BMA280 the max frequency achievable is 2Khz (Unfiltered - data) meaning that it even recognises the noise, But the maximum resolution achievable is 2g- with just 16bits of acceleration bits. The Tap sense on the other hand has to be with least possible resolution say at least a 16g with less frequency. If both the TAP and Accelerometer data is being taken at same frequency the accuracy with which the user uses the device will be completely undetermined.
With High frequency and more resolution, the tap sense has to be very fast that it recognises it as double tap, even with slightest latency it is considered as a data rather than tap sense.
With least frequency and less resolution, the accelerometer values will never be taken, and we end up getting very few data points - which is never enough for the machine learning algorithm.

Solution to Hardware issue:
This is the issue with the selection of the integrated sensor, we have no solution for the implementation now, but in future work, we can implement different effective sensors for each functionality

Functionality of the Final Project:

Two layer PCB design with optimum component density and desired functionality of the sensors are designed and brought up. We have tried achieving all the functionalities as proposed

The prototype uses a battery to provide power to our device. The battery is charged using inductive charging (wireless charging) which is a trending technology in the present day to charge cell phones.
We have alternate USB charging to charge the device in case of failure of inductive charging as a back-up charging circuit.
Our prototype works at 2.5 V ( as compared to 3.3 V) which reduces the energy consumption.
We have used GPIO pin to power our sensor for load power management to achieve low power.
The sensor use SPI interface to interface with the MCU.
Double tap sense of the sensor enables the entire device for use.
After the tap, the user movements are recorded by the accelerometer sensor, it is sent to the application and it is trained by the machine learning algorithm to interpret the data and display it on the application.
In the mean while, temperature sensor , obtains the ambient temperature and sends it to the application and displays the same.

Wow Factor:

- With this product, we did not restrict ourselves to just the complex-Hardware implementation, the challenge flows even to the Software part of the project. We have implemented Machine Learning to recognise the characters by the accelerometer data being received from the accelerometer through the BLE. Our product shares equal complexity in both Hardware and Software and we have achieved both
- Another wow factor is that we have obtained a great density of the board, and as both of us being beginners in this domain, we are very proud to obtain this density and obtain the smallest size of the board in the class.

- Studying on Bluetooth Mesh which is a new technology and try to implement a simple functionality on our board.
- Attempting inductive charging which is not very common energy harvesting technique used for this class and getting it to work according to our project requirement is what we would consider as another wow factor.Inductive charging is one of the trending technology being used in the present day and we are glad to have got an opportunity to work on it.

Future Work

1. To use different effective sensors to achieve modularity and ease of use in different functionalities.
2. To test the machine learning algorithms in different planes and make it more robust in regression-based recognition
3. Once Silicon releases a mode to integration of BLE sdks with BLE MESH sdk, we can define each character recognised to a command and send the commands through BLE MESH. Since we already developed all three APPs and the Back-end code for the functionality, integrating BLE MESH with BLE will and should not take much time to implement.

References
1. https://datascience.stackexchange.com/questions/8732/algorithm-for-gesture-classification-in-a-wearable (https://datascience.stackexchange.com/questions/8732/algorithm-for-gesture-classification-in-a-wearable)
2. https://powerbyproxi.com/wireless-charging/
3. https://www.youtube.com/watch?v=mRAWrXePAw0
4. https://www.technologyreview.com/s/601461/wireless-charging-is-actually-charging-ahead/ (https://www.technologyreview.com/s/601461/wireless-charging-is-actually-charging-ahead/)
5. Bluetooth Mesh Networking/ An Introduction to Developers by Martin Woolley
6. http://www.lipolbattery.com/lithium%20polymer%20battery.html
7. https://milliamps-watts.appspot.com/

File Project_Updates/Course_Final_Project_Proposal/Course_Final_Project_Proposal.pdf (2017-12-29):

### LOW POWER EMBEDDED DESIGN FINAL COURSE PROJECT PROPOSAL

Team Name: WearTech

Team Mates:

Sanjana Kalyanappagol | Shekhar Satyanarayana
saka2821@colorado.edu | shsa5563@colorado.edu

### 1. What is the problem that this project is attempting to solve? How is this

project going to solve this problem?

A wearable ring/cap which is used to take short notes and control other devices through the movements defined in the Mobile App.
With the advent of technology, it is bane to open your mobile/laptop/book to take a note of something important that strikes you all of a sudden or take a phone number of someone you meet unexpectedly. Say you are in a harsh environment, What if you had a wearable device with you all the time as a look-out for such situations.
In the Corporate world, say you are in a meeting and you need to take notes, rather than using notes/pens and disturbing others you can easily take notes of all the important points you need. Say in an unanticipated meeting, wouldn't you feel more secure,safe and confident with our device always at help.
In the field of Software Development & maintenance, one can face a lot of issues/bugs to be fixed within due dates. And with that constantly in mind, Most of us get solutions to the same when we are involved in our day-today activities such as driving,eating,talking with a friend, etc. Hence we would end up looking for a pen & paper, if not we would waste time memorising the solution we had just found unless we have this device around which can keep a record of every thought that you want to be saved at any point of time.
Now with the buzz of IoT we have seen a lot of devices which could communicate with our home appliances. We provide an integrated solution with the new Bluetooth Mesh Network, the Ring/Cap a single device which controls the home appliances and act as a note taker.
The end-applications to such a device is enormous, it can be used to define the movement of a wheelchair, or used by old people/patients to communicate.

### 2. Use case described

Use Case Model to charge energy storage device:

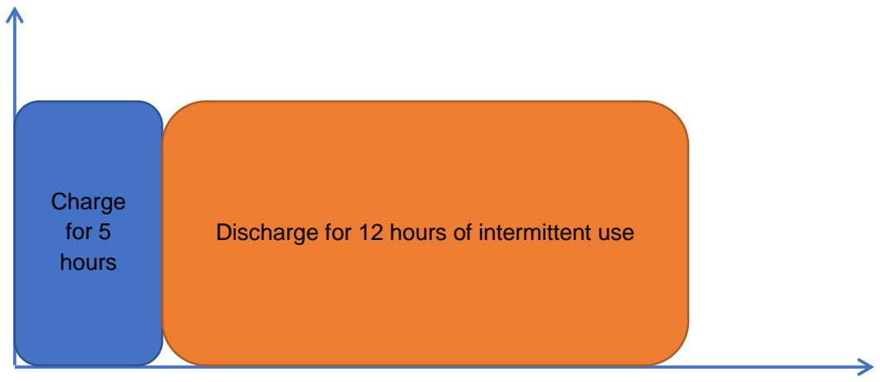
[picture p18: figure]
Charge for 5 hours

5hrs | 12hrs | Time -> (hrs)

Stage 1: The battery is of .2C standard charge capacity, thus to charge fully it will take 5 hours

Stage 2: As per our use case, we need the device to be usable for at the most 12hrs.

### 3. Hardware functional block diagram

Discharge for 12 hours of intermittent use

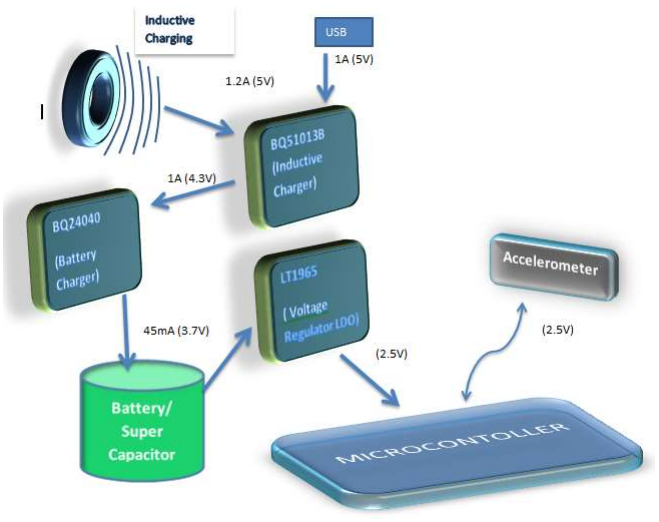
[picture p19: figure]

### 4. List of key hardware components to be used

Part Selection
Battery | GMB401215-45mAh
PMU IC | LT1965
Processor | EFR32BG13– f1024
Inductive Charging IC | BQ5103B
Battery Charger IC | BQ24040
Sensor | BMA280

As discussed, our project requires 2 Blue Gecko dev kits to act as devices in the mesh network.

### 5. Software functional block diagram

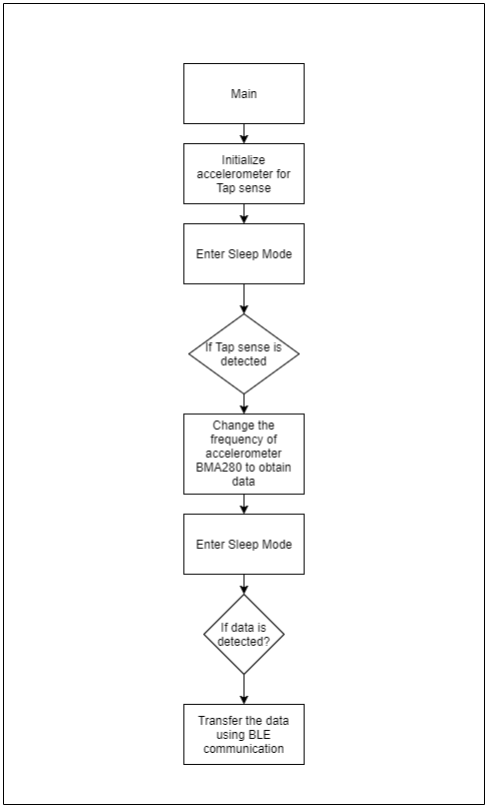
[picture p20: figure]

### 6. What aspects of the project are considered high risk? How is this risk

planned to be mitigated?

Risk factors:

1. We might end up consuming more current because we are using accelerometer (BMA280) to both turn on the entire device and for data acquisition.
2. Our project involves inductive charging for the battery which is a new concept for us and we are not sure if we will be able to get the appropriate energy requirements from inductive charging as required by our application.
3. The issue with accelerometer data acquisition is that we might not know how much data is enough /less to compute the algorithm on the data and detect the pattern or the command
4. The Machine learning algorithms always need more information about the data to differentiate different patterns accurately. And for such high data handling it needs more high powered CPUs, which would help in computing the algorithms on the data in few milliseconds
5. The main problem is the time it takes to capture the data and send the data to either Phone/Cloud => process the data through FTT/any other algorithms to make sense out of the data and pass it through the pattern detector and predict a most accurate command. - All these have to happen within few miliseconds, if not the product can fail
6. The Bluetooth mesh network is a new technology which needs a lot of time to understand and troubleshoot the issue faced.

Mitigation:
1. We are currently using accelerometer (BMA280) in low power 2 mode with 0.5 ms of sleep duration. So, we can considering reducing the current consumption either by increasing the sleep duration or using the accelerometer in a mode with lesser current than low power 2 mode.
2. We will focus on referring more documents and articles on inductive charging to get the required energy requirements. If we are beyond the schedule and still not successful with inductive charging, then we will consider switching to an alternative power source such as USB charging.
3. To know how much data is enough/ less from the accelerometer, we have found out a simple solution to configure a simple app from the mobile (all mobiles have a accelerometer and a gyroscope).
We take the values of the mobile-accelerometer through a simple javascript application, populate the data to a csv-file/ populate the data in realtime to the algorithm we are generating. Thus before the firmware development we will have a clear idea on how much data would be required for acquisition.
4. We are trying to get a simpler lightweight Machine learning algorithm -which can run on a smartphone. If we cannot find the exact configuration we need, we will try dumping the data to any cloud platform to do the work for us - say AWS/IBM Watson etc..
5. Since it is considered as a prototype, even with a max delay to recognise the commands, the minimal success would be to achieve a command. Thus if the commands are recognised we can go ahead and start mitigating the delay.
6. We will focus on configuring only 1 or 2 devices with Bluetooth mesh network to make a simple network by referring documentations and receiving guidance from people who have worked on Bluetooth mesh network. If we are unable to achieve Bluetooth mesh network in the required time then we will consider using ZigBee/WiFi.

### 7. Project Update special topics: 7.1.1 Energy use mode model


Stage 1:
Configuring the Accelerometer for double tap sense (3-5ms)
State 2:
MCU is off, Sensor #1 i.e Accelerometer tap sense is On and it is waiting for an interrupt to switch on the entire device. The device stays in this state for about 3-5 ms after the user has used touch sense to switch on the device. It uses SPI serial port interface which works in EM3 for Blue Gecko and also, we wait for an interrupt in EM3 energy mode.
State 3: MCU becomes on when an interrupt occurs, hence it will be in EM0 mode. In the interrupt service routine (Accelerometer data acquisition) is switched on. This state will take about 10 ms to handle the interrupt and configure the Accelerometer to accept the Data acquisition at higher frequency.
State 4:
In this state, MCU is off while Accelerometer is waiting for an interrupt i.e it is waiting to receive data from the user. As use case considered is when user switches on the device and immediately writes the data, this state will approximately take 1-3 ms.
State 5:
In this state, MCU becomes on when an interrupt occurs i.e when data is received from the user and the data is processed. This state will approximately take 40 ms to handle the interrupt and process the data. State 6:
In this state, the data is transmitted to the mobile phone using BLE and it is interpreted to display the character received. This will take about 70 ms and operates in EM1 for transmission.

### 7.1.2 Calculations to specify the Energy Storage Device

- Average current / energy capacity calculation

Determining the average weighted power out of battery using Blue Gecko:

On duty cycle:
Assuming that the blue gecko is given a input voltage of ~2.5v and ~1.9v is an output voltage.
Blue Gecko’s efficiency at ~2.5v input to ~1.9v out is 2.5v/1.9v = 75.75% Since it cannot be a 75.75% ,
Weighted average power out of battery = (On duty cycle * On time current * 2.5v) / 75.75% = (0.2 * 10.826mA * 2.5v) / 75.75%
Weighted average power out of battery = 71.70 uW

Off duty cycle:
Blue Gecko efficiency at ~3.3 input to ~2.5v out is 2.5v/3.3v = 75.75% Weighted average power out of battery = (Off duty cycle * Off time current* 2.5v) / 75.75% = (98.8 * 0.133mA * 2.5v) / 75.75%
Weighted average power out of battery = 433.68 uW

Total average power out = Weighted on duty cycle average power + Weighted off duty cycle average power
= 71.70 uW + 433.68 uW
= 505.38uW

Average energy the battery must provide on the use case: = 12 hrs of use * 60 mins * 60 secs * 505.38uW
= 21.83J

- Peak currents and Peak current step functions that will need to be considered

BQ51013B has an inductive charging: the max current from the coil can be 1A
USB : the max current from the USB is 1A

The MAX current the BQ24040 (Battery Charger) & BQ51013B (Inductive charging) can handle is 1.245A

The Energy Harvester input doesn’t require any current limiting circuit.

### 7.1.3 Engineering reasons why the particular Energy Storage Device has

been selected
- Number of recharge cycles
- Provide supporting documentation that the use case number of recharge cycles can be achieved.

As per our calculation, we need a battery with the following specifications:
Average energy 21.83J
Vout from the Battery is ≈ 3.3v
Max current required 10.826mA (all on - MCU, Sensors, BLE)
If the product is targeted to be used for 1.5years , 5 days a week. We have 390 recharge cycles.
With weighted average power = (0.2% *10.826mA) + (99.8% * 0.133mA) = 15.439mA
15.439mA * 12 (->12 hours) = 1.83mAh
For rechargeable cells the battery nominal capacity should be 10x capacity.
Thus total =>18.3mAh

We need a battery with 18.3mAh and 21.83J
Thus | selected: | https://www.powerstream.com/lip/GMB401215-
45mAh_With%20PCM_A0.pdf (https://www.powerstream.com/lip/GMB401215-45mAh_With%20PCM_A0.pdf)

Above calculations substantiates the choice of the Energy source to be Battery and not Super-Capacitor.
Batteries provide consistent voltage (3.7 V) - which is within the voltage range of the components we are using in our application. Since our application does not require any bursts of current and we need our device to discharge the power for a long time - we choose Battery.

### 7.1.4 Why is the particular MCU / SoC / Radio being proposed?

EFR32BG13 is chosen since it has the supported sdk for Bluetooth Mesh

### 7.1.5 Why is the particular PMU solution being proposed?

We are researching for Inductive Charging, BQ51013B is the best available TI IC for inductive charging which also supports alternative USB charge mechanism.
BQ24040 is required to charge the LiPo battery from the BQ51013B. LT1965 is chosen to regulate the voltage at 2.5V, which is provided to the MCU.

### 7.1.6 Supporting documentation that voltage droops due to possible current

delta functions of this low energy mode device have been engineered not to result in a failure
a.At Vin = min

Yes, the voltage was increased of about 0.1mV. The Supply Voltage was about 3.28V to the PMU IC from the battery.
The PMU IC would be giving approximately 2.5V output.

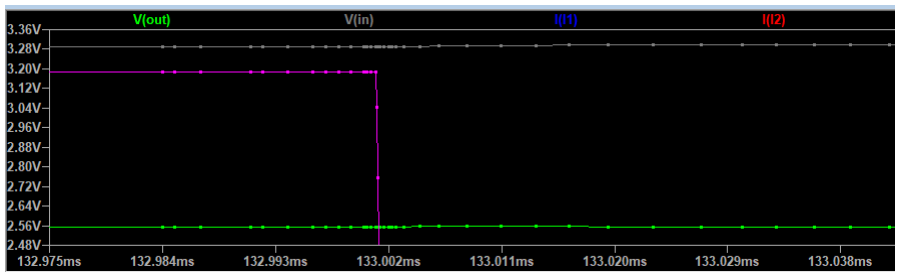
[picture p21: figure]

Note: The silver line indicates the stabilized voltage change

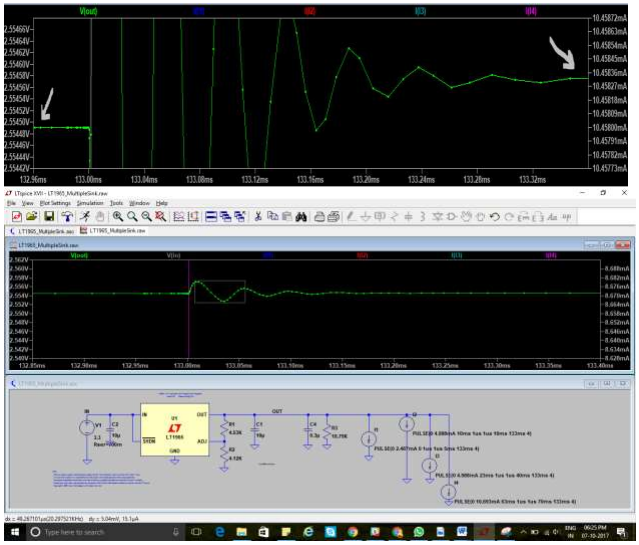
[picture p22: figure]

5mV is the ripple which is within the specifications of 0.5Vp-p

When the dynamic load is added there is a dip in the voltage, the min value is 2.553V, the appropriate voltage supplied by the battery is 3.296V
The Stabilized output voltage of the battery before the dynamic load was 2.5544V Thus, there is a variation of 2.5544-2.553 = 0.0014V => 1.4mV which is within the specifications.

Dynamic current step up load:

Yes, there was a voltage dip with dynamic step up load.

Below screenshot shows the voltage dip when there is dynamic current step up load i.e when the load switches from EM0- Accelerometer interrupt to EM1-BLE transmission.

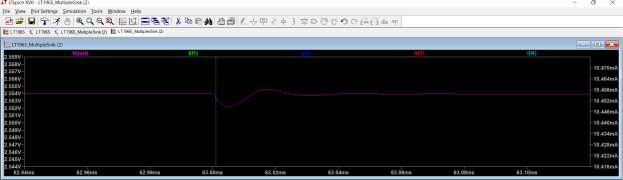
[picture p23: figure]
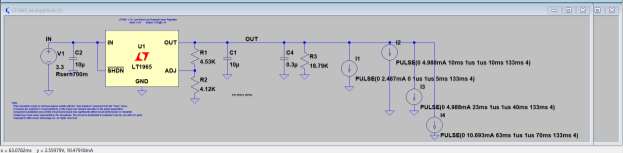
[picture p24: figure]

Minimum out voltage is 2.552167 V Therefore, voltage droop = 1.83 mV < 0.5Vp-p
Hence, this is within the IC specifications

The stabilized voltage in EM0 before dynamic step up load = 2.55399 V The stabilized voltage in EM1 after dynamic step up load = 2.55394 V

b. At Vin = max i.e Vin = 4.2 V

Dynamic current step up function load:

Yes, there was a voltage dip with dynamic step up load.

Below screenshot shows the voltage dip when there is dynamic current step up load i.ewhen the load switches from EM0- Accelerometer interrupt to EM1-BLE transmission.


Minimum out voltage is 2.5516 V Therefore, voltage droop = 1.8 mV < 0.5Vp-p
Hence, this is within the IC specifications

The stabilized voltage in EM0 before dynamic step up load = 2.5534 V The stabilized voltage in EM1 after dynamic step up load = 2.5533 V


For Step Down Load: Vin: Max : 4.2V

The ripple voltage is about 4.5mV, there is a voltage raise of about 1mV indicated by the arrows for step down function.

Vdd:

The Vdd was increased to about 5mV to 4.198v
When the dynamic load is added, a voltage dropped to about 2.5522V, the stabilised voltage before the variation was 2.55407V

The difference of about 1.87mV
Which is within the specifications of 0.5Vp-p ripple. Simulation for with & without Dynamic load:


The circuits as shown above:
Voltage when there is no dynamic load: 2.5542 V (Image on the right)
Voltage when there is dynamic load: 2.5542 V (Image on the left)
Hence there is no change in the voltage when a dynamic load is added to the circuit. The min voltage when the power supply is drooping is 2.53 V which is within the specifications of the IC.

### 7.1.7 Proper engineering selection of the required bulk or PMU ceramic load

capacitance

The value of Decoupling Cap is calculated as the project’s circuit doesn’t require any Bulk load capacitance (Thus not taken into consideration) Decoupling capacitors:

Blue Gecko: According to hardware considerations, we have considered a decoupling capacitor (ceramic capacitor) of value 0.1 uF Ref:https://www.silabs.com/documents/public/applicationnotes/an0002.1-efr32-efm32-series-1-hardware-designconsiderations.pdf (https://www.silabs.com/documents/public/application-notes/an0002.1-efr32-efm32-series-1-hardware-design-considerations.pdf)

BMA280: We have considered a decoupling two capacitors of 100 nF( 0.1 Uf each).
Ref: | http://www.mouser.com/ds/2/783/BST-BMA280-DS000-
11_published-786496.pdf (http://www.mouser.com/ds/2/783/BST-BMA280-DS000-11_published-786496.pdf)

Hence total capacitance = 0.3 uF

Thus, the capacitance for the power plane is the same value as the decoupling capacitor of 0.3uF.


According to the Data sheet of LT1965:

And also ceramic capacitor of type X5R is preferred according to the data sheet of PMU and for the decoupling capacitors for MCU and accelerometer sensor.
Ref: https://www.silabs.com/documents/public/applicationnotes/an0002.1-efr32-efm32-series-1-hardware-designconsiderations.pdf (https://www.silabs.com/documents/public/application-notes/an0002.1-efr32-efm32-series-1-hardware-design-considerations.pdf)
http://cds.linear.com/docs/en/datasheet/1965fb.pdf

Considering the DC-Bias characteristics, we have selected the below part-number for the load capactior which would suffice with the condition given in the datasheet (min of 10uF for the load capacitor)

We have a decoupling capacitor of 0.3 uF. Considering the DC-Bias characteristics, we have selected the below part-number for the load capactior which would suffice the requirement.

We have a decoupling capacitor of 0.1 uF each at each volatage terminal of BMA280 and PMU.

Selected part number to give a capacitance of 0.1UF at 2.5V which is our working voltage is :
http://psearch.en.murata.com/capacitor/product/GRM188R71C104KA0 1%23.html (http://psearch.en.murata.com/capacitor/product/GRM188R71C104KA01%23.html)


Ref: http://cds.linear.com/docs/en/datasheet/1965fb.pdf

### 7.1.8 ESD protection has been engineered on these user accessible lines to

ensure a long-life product

A TVS DIODE 5VWM 12.5VC SC88 is selected for the power lines from the USB, the inductive charging does not need any ESD diodes. Since the BMA 280 is on the board, we do not need any ESD diodes for the communication.

### 7.1.9 Verification plan

To be verified | Definition of passing | Date test performed | Tested by | Measur ed result | Passed ?
Supply voltage to the MCU should be within the minimum and maximum specification | The voltage should be within 1.8V to 3.3 V
Supply voltage to the BMA280 sensor using SPI interface should be within the minimum and maximum specifications | The voltage should be within 1.2V to 3.6 V
Signal quality of SPI communication line | Check correct signal level transition on the oscilloscope

Firmware Block
of | BMA280
using | SPI
interface: | The
MCUis receiving
correct data
from the sensor
The | interrupt
should | | get
triggered
whenever | the
sensor | senses
data.
The | MCU | is
receiving | the
correct
accelerometer
reading from the
sensor- verify
clock too.
Verify | | Chip
Select | of | SPI
goes low while
transferring data
The radio is transmitting data correctly | Verify at the receiver’s end the data received
Supply voltage | The voltage

from the USB | should be within 4.3 to 5 V
Supply current from the Inductive coil | 50mA to 1A
The Current out from the Inductive Charger – BQ51013B | 1.1 to 1.2A
The Current input to the BQ24040 | 1.1 to 1.245 A
The Voltage at the RECT pin | Must be within 4.3 to 5V
The voltage at the BAT Pin/VOUT from BQ24040 | 3.5 to 4.2V
The current at the BAT Pin/VOUT BQ24040 | 45mA +/- 10%
The voltage input to the LDO LT1965 | 1.8 to 20 V
The voltage output from the LDO to MCU | 2.5V exact

References

1. https://datascience.stackexchange.com/questions/8732/algorithm-for-gestureclassification-in-a-wearable (https://datascience.stackexchange.com/questions/8732/algorithm-for-gesture-classification-in-a-wearable)
2. https://powerbyproxi.com/wireless-charging/
3. https://www.youtube.com/watch?v=mRAWrXePAw0
4. https://www.technologyreview.com/s/601461/wireless-charging-is-actually-chargingahead/ (https://www.technologyreview.com/s/601461/wireless-charging-is-actually-charging-ahead/)
5. Bluetooth Mesh Networking/ An Introduction to Developers by Martin Woolley
6. http://www.lipolbattery.com/lithium%20polymer%20battery.html
7. https://milliamps-watts.appspot.com/

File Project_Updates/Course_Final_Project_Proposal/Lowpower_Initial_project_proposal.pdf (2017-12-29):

# LOW POWER EMBEDDED DESIGN PROJECT PROPOSAL

### Team Name : WearTech

### Team Mates:

Sanjana Kalyanappagol | Shekhar Satyanarayana
saka2821@colorado.edu | shsa5563@colorado.edu

## Introduction

What is the Project: A wearable ring/cap which is used to take short notes and control other devices through the movements defined in the Mobile App.

What problem does the project solve? Or, what value does it provide? : With the advent of technology, it is bane to open your mobile/laptop/book to take a note of something important that strikes you all of a sudden or take a phone number of someone you meet unexpectedly. Say you are in a harsh environment, What if you had a wearable device with you all the time as a look-out for such situations.
In the Corporate world, say you are in a meeting and you need to take notes, rather than using notes/pens and disturbing others you can easily take notes of all the important points you need. Say in an unanticipated meeting, wouldn't you feel more secure,safe and confident with our device always at help.
In the field of Software Development & maintenance, one can face a lot of issues/bugs to be fixed within due dates. And with that constantly in mind, Most of us get solutions to the same when we are involved in our day-to-day activities such as driving,eating,talking with a friend, etc. Hence we would end up looking for a pen & paper, if not we would waste time memorising the solution we had just found unless we have this device around which can keep a record of
every | thought | that | you | want | to | be | saved | at | any | point | of | time.
Now with the buzz of IoT we have seen a lot of devices which could communicate with our home appliances. We provide an integrated solution with the new Bluetooth Mesh Network, the Ring/Cap a single device which controls the home appliances and be a note taker. The end-applications to such a device are enormous, it can be used to define the movement of a wheelchair, it can be used by old people/patients to communicate.

## Block Diagram


## Key Critical Requirements

Battery Life Requirements: Since we are targeting for a prototype of the device, we presume we can limit to a battery life of 2hours.

End product physical dimensions: The product is a wearable thus, as small a device can be would be best. But since it is a prototype we can limit within 3”x 5”

Other Requirements:
Wireless charging - Inductive charging.
The movement of the accelerometer recorded must be processed with less margin of error and detect the exact character/gesture.
The Ring/Cap should communicate & control other devices in the Bluetooth mesh (Say a simple on/off)

## Key Blocks

Microcontroller: Blue gecko
Radio Technology: BLE/ Bluetooth Mesh
Energy harvesting : Inductive charging of capacitor/battery through Power sockets.

## Guidance

Prof.Keith Graham : Insights on wireless charging, bluetooth mesh network

## References

1. https://datascience.stackexchange.com/questions/8732/algorithm-for-gestureclassification-in-a-wearable (https://datascience.stackexchange.com/questions/8732/algorithm-for-gesture-classification-in-a-wearable)
2. https://powerbyproxi.com/wireless-charging/
3. https://www.youtube.com/watch?v=mRAWrXePAw0
4. https://www.technologyreview.com/s/601461/wireless-charging-is-actually-chargingahead/ (https://www.technologyreview.com/s/601461/wireless-charging-is-actually-charging-ahead/)
5. Bluetooth Mesh Networking/ An Introduction to Developers by Martin Woolley

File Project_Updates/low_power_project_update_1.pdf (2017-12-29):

# LOW POWER EMBEDDED DESIGN PROJECT UPDATE #1

### Team Name : WearTech

### Team Mates:

Sanjana Kalyanappagol | Shekhar Satyanarayana
saka2821@colorado.edu | shsa5563@colorado.edu

Components Required:
- Processor: Blue gecko BGM11S module
- As discussed, our project requires 2 Blue Gecko dev kits to act as devices in the mesh network.
- Sensor: Triple Axis Accelerometer ADXL345
- Sensor: Capacitive sense PCF8885

Part Selection:
Processor: Blue gecko BGM11S module
We chose this processor because it supports Bluetooth mesh networking and has higher range for communication.
https://www.silabs.com/products/wireless/bluetooth/bluetooth-low-energy-modules/bgm11s-bluetooth-sip-module (https://www.silabs.com/products/wireless/bluetooth/bluetooth-low-energy-modules/bgm11s-bluetooth-sip-module)

Sensor: Triple Axis Accelerometer ADXL345
We chose this sensor because accelerometer plays an important role in the project to identify characters / command given by the user. This sensor could be used to obtain data according to each axis readings and then process the data to identify the character.
Serial port interface: I2C. Blue Gecko has two I2C interfaces available.
Power supply: This sensor requires regulated power supply.

Features and Benefits:
- Ultralow power: as low as 40 μA in measurement mode and 0.1 μA in standby mode at VS = 2.5 V (typical)
- Power consumption scales automatically with bandwidth
- User-selectable resolution
- Fixed 10-bit resolution
- Full resolution, where resolution increases with g range, up to 13-bit resolution at ±16 g (maintaining 4 mg/LSB scale factor in all g ranges)
- Embedded, patent pending FIFO technology minimizes host processor load
- Tap/double tap detection
- Activity/inactivity monitoring
- Free-fall detection
- Supply voltage range: 2.0 V to 3.6 V
- I/O voltage range: 1.7 V to VS
- SPI (3- and 4-wire) and I2C digital interfaces
- Flexible interrupt modes mappable to either interrupt pin
- Measurement ranges selectable via serial command
- Bandwidth selectable via serial command
- Wide temperature range (−40°C to +85°C)
- 10,000 g shock survival
- Pb free/RoHS compliant
- Small and thin: 3 mm × 5 mm × 1 mm LGA package

Why this sensor? Why not MMA8542Q?
This sensor is a ultralow power sensor. It’s stand-by mode current is 0.1uA and 40uA in measurement mode which is less as compared to MMA8542Q sensor.
Load power management can be performed as its supports different energy modes.In Blue gecko, the I2C can perform address recognition in EM3-Stop mode.

It is an interrupt driven sensor so the MCU is turned on and processes the data only when we receive data via I2C on a GPIO pin.

Sensor: Capacitive sense PCF8885

Why this sensor?
Capacitive 8-channel touch and proximity sensor with auto-calibration and very low power consumption. The integrated circuit PCF8885 is a capacitive 8-channel touch and proximity sensor that uses a patented (EDISEN) method to detect a change in capacitance on remote sensing plates. Changes in the static capacitances (as opposed to dynamic capacitance changes) are automatically compensated using continuous auto-calibration. Remote sensing plates (for example, conductive foils) can be connected to the IC1 using coaxial cable. The eight input channels operate independently of each other. There is also a built-in option for a matrix arrangement of the sensors: interrupt generation only when two channels are activated simultaneously, suppression of additional channel outputs when two channels are already active.

The Capacitive sensor is interrupt driven. This sensor uses regulated power supply.

Why Not SparkFun - AT42QT1010 for Capacitive sense?
1. Even though the AT42QT1010 is low power capacitive sense , it does not use I2C communication. Even the current is more compared to the PCF8885

Features and Benefits:

- Dynamic touch and proximity sensor with 8 sensor channels
- Support for matrix arrangement of sensors
- Sensing plates can be connected remotely
- Adjustable response time
- Adjustable sensitivity
- Continuous auto-calibration
- Digital processing method
- Can cope with up to 6 mm of acrylic glass
- Direct and latching switch modes
- I 2C Fast-mode Plus (Fm+) compatible interface
- Two I2C-bus addresses
- Cascading of two ICs possible
- Interrupt signalling over I2C-bus
- Large voltage operating range (VDD = 2.5 V to 5.5 V)
- Sleep mode (IDD < 100 nA)
- Low-power battery operation possible (IDD ~ 10 A)
- Operating temperature range (Tamb = 40 C to +85 C)
- Available in TSSOP28 and SOIC28 package

Radio Communication:
Chosen communication : Bluetooth Low Energy, Bluetooth and Bluetooth Mesh Network.
Why Bluetooth Technology?
1. Bluetooth technology is most secure and is resistant to other radio communications like wifi/zigbee and even ANT. Since it has more resistance to interference from other technologies, we opted BLE.

2. Since Bluetooth Mesh is a new technology, this course and project provide us an opportunity to explore it. Thus not exploring thread/zigbee mesh networks.
3. With Wifi, we would be using a lot of power as compared to BLE. Our project does not need a higher bandwidth communication technology, thus wifi is not a good option.

Use Case Model:

Use case model 1:

(In terms of a single day usage from the customer/user)
Considering a person who sleeps for 8hrs, making a total of 16hrs of the day in which our device should be in on-state.
With a generic user, if we presume that the device would be used for almost 8hrs in a day.
Assuming an ideal user, who would switch on the device and start using it/ does no actions for 10seconds after switching on the device.


T1: The MCU can wait for an interrupt for a stretch of 16 hrs
T2 : Once Interrupt of Sensor #1 is occurred the MCU is on for 10ms to process the information and turn on the sensor #2
T3 : Once the sensor #2 is switched on, the MCU would be in sleep mode waiting for interrupts from Sensor #1 & Sensor#2. If we have received no interrupt from Sensor#2 after say 10seconds, we will

disable the sensor#2.
[The User might switch on the device and never do any action till the next 10seconds, thus we are making sure that the accelerometer is turned off if no actions are captured from sensor#2 after 10seconds]
T4: Once we have received the data from the user, the interrupt is generated and we process the data. This approximately takes around 30ms to process the data.
T5: The processed data has to be sent to the mobile Application within the approximate 70ms.

Note:
1. For this use case the worst case time is considered.
2. After the data is transmitted through BLE, the mobile device should accept the connection and start processing the data. And take according actions/ record the actions. All these has to be computed and accomplished in realtime, thus should take as less time as possible, say within a second.

Use Case Model 2:


Use Case model condition: When the user switches on the device and immediately sends the data (performs an action)

State 1: MCU is off, Sensor #1 i.e Capacitive sense is On and it is waiting for an interrupt to switch on the entire device. The device stays in this state for about 3-10 ms after the user has used touch sense to switch on the device. The capacitive sense we have chosen uses I2Cs serial port interface which works in EM3 for Blue Gecko and also, we wait for an interrupt in EM3 energy mode.

State 2: MCU becomes on when an interrupt occurs, hence it will be in EM0 mode. In the interrupt service routine sensor #2(Accelerometer) is switched on. This state will take about 10 ms to handle the interrupt and switch on sensor #2.

State 3: In this state, MCU is off while sensor #1 and sensor #2 are on. Sensor #2 is waiting for an interrupt i.e sensor #2 is waiting to receive data from the user. As use case considered is when user switches on the device and immediately writes the data, this state will approximately take 1-3 ms.

State 4: In this state, MCU becomes on when an interrupt occurs i.e when data is received from the user and the data is processed. This state will approximately take 40 ms to handle the interrupt and process the data.

State 5: In this state, the data is transmitted to the mobile phone using BLE and it is interpreted to display the character received. This will take about 70 ms.

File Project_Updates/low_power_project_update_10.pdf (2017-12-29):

## LOW POWER EMBEDDED DESIGN PROJECT UPDATE #10

Team Name: WearTech

Team Mates:

Sanjana Kalyanappagol | Shekhar Satyanarayana
saka2821@colorado.edu | shsa5563@colorado.edu

## Executive Summary:

Part Selection
Battery | GMB401215-45mAh
PMU IC | LT1965
Processor | EFR32BG13– f1024
Inductive Charging IC | BQ5103B
Battery Charger IC | BQ24040
Sensor | BMA280

As discussed, our project requires 2 Blue Gecko dev kits to act as devices in the mesh network.

On Schedule: Yes

Accomplishments:
- Completed Layout reviews
- Ordered the components and Board
- Continue to work on firmware

Next week:
- Place components
- Test Inductive charging
- Test the board connectivity for all the signals

### What is the max current of your energy harvesting source?

### BQ51013B has an - inductive charging : the max current from the coil can be 1A - USB : the max current from the USB is 1A

### What is the max current that the PMU circuit can handle from the Energy Harvester?

### The MAX current the BQ24040 (Battery Charger) & BQ51013B (Inductive charging) can handle is 1.245A

### Does the Energy Harvester input require current limiting circuit?

### No, it is always within the limits

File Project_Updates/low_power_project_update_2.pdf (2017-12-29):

# LOW POWER EMBEDDED DESIGN PROJECT UPDATE #2

### Team Name : WearTech

### Team Mates:

Sanjana Kalyanappagol | Shekhar Satyanarayana
saka2821@colorado.edu | shsa5563@colorado.edu

## Part Selection:

Battery | : LIPO 785060, 2500 mAH
PMU IC | : LT1121
Processor | : Blue gecko BGM11S module

### As discussed, our project requires 2 Blue Gecko dev kits to act as devices in the

mesh network.
Sensor1 | : Triple Axis Accelerometer ADXL345
Sensor2 | : Capacitive sense PCF8885

Table 1: Energy modes vs Current Consumption of Blue Gecko:

Energy modes | Current Consumption
EM0 | 130 uA
EM1 | 65 uA
EM2 | 3.3 uA
EM3 | 2.8 uA
EM4 | 1.1 uA

Table 2: Voltage and Current of all components:

Device | On Duty Cycle Current | Off Duty Cycle Current | Supply Voltage | Input Voltage
Blue Gecko (MCU) | EM0: 130 uA /MHz | EM3: 2.8 uA | 2.4 - 3.8 V
Cap Sense | 20 uA | 500 nA (Typical 100 nA) | 2.5 - 5.5 V | 2.5 to 3.3 V
Accelerometer | 145 uA(100 Hz) , 40uA(<10Hz) | 0.1 uA | 2- 3.6 V | 1.7V -Vs(Typ 1.8V) (Vs<=2.5) 2.0V- Vs(Typ 2.5) (Vs>=2.5)
BLE Radio Communication | 8.2 mA( 0 db) | - | - | -

Use Case Model:


Use Case model condition: When the user switches on the device and immediately sends the data (does an action)

State 1: MCU is off, Sensor #1 i.e Capacitive sense is On and it is waiting for an interrupt to switch on the entire device. The device stays in this state for about 3-5 ms after the user has used touch sense to switch on the device. The capacitive sense we have chosen uses I2Cs serial port interface which works in EM3 for Blue Gecko and also, we wait for an interrupt in EM3 energy mode.

State 2: MCU becomes on when an interrupt occurs, hence it will be in EM0 mode. In the interrupt service routine sensor #2(Accelerometer) is switched on. This state will take about 10 ms to handle the interrupt and switch on sensor #2.

State 3: In this state, MCU is off while sensor #1 and sensor #2 are on. Sensor #2 is waiting for an interrupt i.e sensor #2 is waiting to receive data from the user. As use case considered is when user switches on the device and immediately writes the data, this state will approximately take 1-3 ms.

State 4: In this state, MCU becomes on when an interrupt occurs i.e when data is received from the user and the data is processed. This state will approximately take 40 ms to handle the interrupt and process the data.

State 5: In this state, the data is transmitted to the mobile phone using BLE and it is interpreted to display the character received. This will take about 70 ms and operates in EM1 for transmission.

Calculations:

Duty cycle:

The worst case time-deduced from the Use Case model- to process a character is 300 ms. Considering an idle user , say a maximum of 50 commands and 200 characters per day is expected.

Total On time of the device = On time for commands(character) + On time for text(string)
= 300ms * 50 + 300 ms * 200 = (15/(60*60)) + (60/ 60 * 60) = 0.0042 hrs + 0.02 hrs
= 0.0242 hrs

The device should be usable for 12 hrs in a day. On duty cycle = 0.0242 /12 => 0.2 %

Hence, Off time of the device = 12 - 0.0242
= 11. 9758 hrs
Off duty cycle = 11. 9758/12 => 99.8 %

Determining the average weighted power out of battery using Blue Gecko:

On duty cycle:
Blue Gecko’s efficiency at ~3.3v input to ~2.5v out is 2.5v/3.3v = 75.75%
Weighted average power out of battery = (On duty cycle * On time current * 2.5v) / 75.75% = (0.2 * 8.495mA * 2.5v) / 75.75% Weighted average power out of battery = 56.07 uW

Off duty cycle:
Blue Gecko efficiency at ~3.3 input to ~2.5v out is 2.5v/3.3v = 75.75%
Weighted average power out of battery = (Off duty cycle * Off time current* 2.5v) / 75.75%
= (98.8 * 3.4 uA * 2.5v) / 75.75% Weighted average power out of battery = 11.086 uW

Total average power out = Weighted on duty cycle average power + Weighted off duty cycle average power
= 56.07 uW + 11.086 uW
= 67.15 uW

Average energy the battery must provide on the use case: = 12 hrs of use * 60 mins * 60 secs * 67.15 uW
= 2.9J

Battery:

As per our calculation, we need a battery with the following specifications:
- Average energy 2.9J
- Vout from the Battery is ≈ 3.3v
- Max current required 8.495mA (all on - MCU, Sensors, BLE)
- If the product is targeted to be used for 1.5years , 5 days a week. We have 390 recharge cycles.
With weighted average power = (0.2% * 8.495m) + (99.8% * 3.4 uA) = 2.03mA
2.03mA * 12 (->12 hours) = 24.36mAh
For rechargeable cells the battery nominal capacity should be 10x capacity
Thus total => 243.6mAh

According to the above specifications we have chosen: (LIPO 785060)Lithium Ion Polymer Battery with 2500mAh & 3.7V output voltage => The energy would be 9.25J



Above calculations (LIPO 785060) substantiates the choice of the Energy source to be Battery and not Super-Capacitor.
Batteries provide consistent voltage (3.3 V) - which is within the voltage range of the components we are using in our application. Since our application does not require any bursts of current and we need our device to discharge the power for a long time - we choose Battery.

Power Management Unit:

In our project, Blue Gecko MCU can be operated at 3.3 V which can in-return drive the sensors with the same 3.3V.
With LiPo Battery of 2500mAh and 3.7V (typical) we have
- Vin= 3.7V(min) to 3.9V(max)
- Vout = 3.3 V.

http://www.linear.com/solutions/ helps us choose PMU with the above specifications.


We have chosen “LT1121 5V Battery-Powered Supply with Shutdown” as our PMU

Features

- 0.4V Dropout Voltage
- 150mA Output Current
- 30µA Quiescent Current

- No Protection Diodes Needed
- Adjustable Output from 3.75V to 30V
- 3.3V and 5V Fixed Output Voltages
- Controlled Quiescent Current in Dropout
- Shutdown
- 16µA Quiescent Current in Shutdown
- Stable with 0.33µF Output Capacitor
- Reverse Battery Protection
- No Reverse Current with Input Low
- Thermal Limiting

More Info :
http://www.linear.com/solutions/4777
http://www.linear.com/product/LT1121http://cds.linear.com/docs/en/datasheet/1121fg.pdf

The battery gives a range of 3.7 to 3.9 output voltage and the PMU is fixed at 3.3v output.
The MCU is driven from the PMU and MCU further drives Accelerometer, CapSense & BLE.
The MCU,sensors,BLE can work in the max-min 2.5V to min-max-3.6V.
Our digital/analog portion does not require a fixed voltage range but we have chosen a 3.3 fixed output voltage from the PMU.
Thus accordingly, we presume the power supply to be a regulated power supply.

Accomplishments:
- We are on schedule for the project.
- We have obtained energy profile determining current in each mode of operation and its functionality.
- We have completed parts selection including energy storage device and power management unit.
- We have calculated the peak current and the amount of energy that has to be supplied to the circuit from the battery.
- We have decided on regulated vs unregulated power supply

Next week:
- Schematics design for the circuit
- Energy spiked calculation
- Simulation of Voltage droop
- We need to work on the Machine Learning Algorithms to see which would be a good fit for data extraction and prediction.

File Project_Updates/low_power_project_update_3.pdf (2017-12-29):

## LOW POWER EMBEDDED DESIGN PROJECT UPDATE #3

Team Name : WearTech

Team Mates:

Sanjana Kalyanappagol | Shekhar Satyanarayana
saka2821@colorado.edu | shsa5563@colorado.edu

## Part Selection:

Battery | : LIPO 785060, 2500 mAH
PMU IC | : LT3008EDC
Processor | : Blue gecko BGM121 module
As discussed, our project requires 2 Blue Gecko dev kits to act as devices in the mesh network.
Sensor | : BMA280

Table 1: Energy modes vs Current Consumption of Blue Gecko:

Energy modes | Current Consumption | Frequency (MHz ) | Total Current
EM0 | 130 uA/MHz | 38.4 | 4.992mA
EM1 | 65 uA/MHz | 38.4 | 2.496mA
EM2 | 3.3 uA | - | 3.3uA
EM3 | 2.8 uA | - | 2.8uA
EM4 | 1.1 uA | - | 1.1uA

Table 2: Voltage and Current of all components:

Device | On Duty Cycle Current | Off Duty Cycle Current | Supply Voltage
Blue Gecko (MCU) | EM0: 130 uA /MHz | EM3: 2.8 uA | 1.85 - 3.8 V
Accelerometer | 130uA at 2kHz sample rate | 129.73uA at 15.63Hz | 1.62- 3.6 V Typical: 2.4
BLE Radio Communication | 8.2 mA( 0 db) | - | -

Calculations:

Accelerometer: Since we need the double tap/single tap to be sensed at lesser frequency in low power as compared to the data acquisition in higher frequency, We have assumed the Accelerometer to work at Low Power 2 mode while sensing double/single tap.

Specifications from BMA280 datasheet:
IDD = 130uA
IDDSBM= 62uA (suspend mode)

(For <31.25Hz)

tut = 32ms
tw,up2 = 1.2ms
tactive = (4*(32) + 1.2-0.9) = 125.9ms
IDDLp2 = ((0.5*62) + (125.9* 130))/(0.5+125.9) => 129.73uA
Normal Mode Current for 2kHz sample rate for unfiltered data is 130uA.

Duty cycle:

The worst case time-deduced from the Use Case model- to process a character is 300 ms. Considering an idle user , say a maximum of 50 commands and 200 characters per day is expected.

Total On time of the device = On time for commands(character) + On time for text(string)
= 300ms * 50 + 300 ms * 200 = (15/(60*60)) + (60/ 60 * 60) = 0.0042 hrs + 0.02 hrs
= 0.0242 hrs

The device should be usable for 12 hrs in a day. On duty cycle = 0.0242 /12 => 0.2 %

Hence, Off time of the device = 12 - 0.0242
= 11. 9758 hrs
Off duty cycle = 11. 9758/12 => 99.8 %

Determining the average weighted power out of battery using Blue Gecko:

On duty cycle:
Assuming that the blue gecko is given a input voltage of ~3.3v and ~2.5v is an output voltage.
Blue Gecko’s efficiency at ~3.3v input to ~2.5v out is 2.5v/3.3v = 75.75%
Weighted average power out of battery = (On duty cycle * On time current * 2.5v) / 75.75%
= (0.2 * 13.322mA * 2.5v) / 75.75% Weighted average power out of battery = 87.96 uW

Off duty cycle:
Blue Gecko efficiency at ~3.3 input to ~2.5v out is 2.5v/3.3v = 75.75%
Weighted average power out of battery = (Off duty cycle * Off time current* 2.5v) / 75.75%
= (98.8 * 0.133mA * 2.5v) / 75.75% Weighted average power out of battery = 433.68 uW

Total average power out = Weighted on duty cycle average power + Weighted off duty cycle average power
= 87.96 uW + 433.68 uW
= 521.64uW

Average energy the battery must provide on the use case: = 12 hrs of use * 60 mins * 60 secs * 521.64uW
= 22.53J => 6259.68 uWh
=> 6.259 mWh

Battery:

As per our calculation, we need a battery with the following specifications:
- Average energy 22.53J
- Vout from the Battery is ≈ 3.3v
- Max current required 13.322mA (all on - MCU, Sensors, BLE)
- If the product is targeted to be used for 1.5years , 5 days a week. We have 390 recharge cycles.
With weighted average power = (0.2% *13.322mA) + (99.8% * 0.133mA) = 15.938mA 15.938mA * 12 (->12 hours) = 191.26mAh

For rechargeable cells the battery nominal capacity should be 10x capacity
Thus total =>1912.6mAh (with 2.5v output) => 4.9025Wh=>

According to the above specifications we have chosen: (LIPO 785060)Lithium Ion Polymer Battery with 2500mAh & 3.7V output voltage
The discharge voltage is at 2.75v thus making a total of 6.875Wh which is within our needs for the battery.

Verify C-Rate:

With 1C Capacity the battery discharges at 54mins with 2.5A as the current 2.75*(54/60)*2.5 = 6.1875J => 1.719Wh

For the total Wh we use in a day of (12 hourse use) => 4.9025Wh; meaning that we can use the device for almost 2 days without recharging, thus in 1.5 years of the use of the product the user can recharge the device 273 times in 1.5 years. The recharge cycles of the battery is 400, which comes within the limits of the
For a total ontime and offtime for

Above calculations (LIPO 785060) substantiates the choice of the Energy source to be Battery and not Super-Capacitor.
Batteries provide consistent voltage (3.3 V) - which is within the voltage range of the components we are using in our application. Since our application does not require any bursts of current and we need our device to discharge the power for a long time - we choose Battery.


With the above info;
What is the C rate of the specified battery?
->0.5C discharge but with 1C discharge is the max, thus considering 1C
What is the peak discharge rate out of the battery?
->1C5
Based on your lithium battery discharge curve, what is the lowest nominal voltage? ->With 1C, the discharge voltage is 2.75V
What will be the battery cut off voltage of your circuit?
-> The circuit needs at a min of 1.85 to max of 3.6V- Considering the Min-Max voltage and Max-Min Voltage, Thus we are considering an optimal/average of 2.75V
Will this nominal voltage require a buck only solution or buck boost?
-> We have 2.5 and 3.3 operable voltage ranges, if we are considering a 3.3V- we need a buck boost circuit. If we use 2.5V as output then the circuit will be simpler and we would not need a buck boost.
What is the voltage that will be programmed as the cut off voltage from the battery of the PMU circuit?
->3.3V /2.5V

Power Management Unit:

In our project, Blue Gecko MCU can be operated at 3.3 V which can in-return drive the sensors with the same 3.3V.
With LiPo Battery of 2500mAh and 3.7V (typical) we have
- Vin= 2.8V(min) to 3.9V(max)
- Vin (min) = 2.8 V as discharge current of the Battery is 2.75 V
- Vout = 3.3 V.

http://www.linear.com/solutions/ helps us choose PMU with the above specifications.

We have chosen “DC1388A - LT3008EDC Demo Board | 3uA Iq, 20mA Low Dropout
Linear Regulators” as our PMU

Features

- Ultralow Quiescent Current: 3μA
- Input Voltage Range: 2.0V to 45V
- Output Current: 20mA
- Dropout Voltage: 300mV
- Adjustable Output (VADJ = VOUT(MIN) = 600mV)
- Fixed Output Voltages: 1.2V, 1.5V, 1.8V, 2.5V, 3.3V, 5V

- Output Tolerance: ±2% Over Load, Line and Temperature
- Stable with Low ESR, Ceramic Output Capacitors (2.2μF Minimum)
- Shutdown Current: <1μA n Current Limit Protection
- Reverse-Battery Protection
- Thermal Limit Protection
- TSOT-23 and 2mm × 2mm DFN Packages

More Info :
http://cds.linear.com/docs/en/datasheet/3008fc.pdfhttp://www.linear.com/product/LT3008

The battery gives a range of 3.7 to 3.9 output voltage and the PMU gives fixed voltage
at | 1.2V, 1.5V, 1.8V, 2.5V, 3.3V, 5V | at output.
The MCU is driven from the PMU and MCU further drives Accelerometer, & BLE.
The MCU,sensors,BLE can work in the max-min 1.85V to min-max-3.6V.
Our digital/analog portion does not require a fixed voltage range but we have chosen a 3.3 fixed output voltage from the PMU. If needed, going further we can reduce the voltage to 2.5V which is within voltage range of Blue Gecko and Accelerometer.
Thus accordingly, we presume the power supply to be a unregulated power supply.
We have not considered any capacitors because as per our calculations and the data sheet there is no current surge.

Worst case timing information on SPI communication bus based on Accelerometer on the SPI bus.

As per SPI information from Accelerometer(BMA280),


The Maximum frequency at which SPI Clk for accelerometer works is 10 MHz because VDDIO for Accelerometer is >1.62 V.


However, when considered the information of SPI Clk of Blue Gecko, The minimum Clk frequency is 1/tsclk, where tsclk = 2 * tHFPERCLK.

tHFPERCLK = 1/fHFPERCLK = 1/16 MHz
tsclk = 2 * (1/16 MHz)
tsclk = 125 ns
fsclk = 1/125 ns = 8 MHz.

Hence considering the above 2 situations the Accelerometer can work at its maximum frequency of 10 MHz.

SPI doesn't use start or stop bits, so there is no 'wasted' signal time. There are only two symbols (high and low), so Baud rate = bit rate, measured in bit/s, kbit/s, Mbit/s, etc (not KBits/s). If the SPI clock is 10MHz, then the bit rate will be 10Mbit/s and if it has to be pre-scaled then it is divided by 2, 4, 8, 16, 32, 64, 128, 256, set by the 'Baud rate control bits.

Hence the worst frequency at which it will operate is 10 Mhz. It can be reduced further according to our convenience.

Reference:

https://electronics.stackexchange.com/questions/260004/spi-how-calculate-baud-rate-through-clock-and-bit-rates (https://electronics.stackexchange.com/questions/260004/spi-how-calculate-baud-rate-through-clock-and-bit-rates)

https://www.silabs.com/documents/login/data-sheets/bgm12x-datasheet.pdf


For Accelerometer:

SDI Hold time: 20 ns(Min)
SDI Setup time: 20 ns (Min) SDO Output Delay: 40 ns (Min)

SPI interface in master mode in Blue Gecko: MISO setup time: 37 ns(Min)
MISO hold time: 6 ns(Min)

Risk factors:

1. We might end up consuming more current because we are using accelerometer (BMA280) to both turn on the entire device and for data acquisition.
2. Our project involves inductive charging for the battery which is a new concept for us and we are not sure if we will be able to get the appropriate energy requirements from inductive charging as required by our application.
3. The issue with accelerometer data acquisition is that we might not know how much data is enough /less to compute the algorithm on the data and detect the pattern or the command
4. The Machine learning algorithms always need more information about the data to differentiate different patterns accurately. And for such high data handling it needs more high powered CPUs, which would help in computing the algorithms on the data in few milliseconds
5. The main problem is the time it takes to capture the data and send the data to either Phone/Cloud => process the data through FTT/any other algorithms to make sense out of the data and pass it through the pattern detector and predict a most accurate command. - All these have to happen within few miliseconds, if not the product can fail
6. The Bluetooth mesh network is a new technology which needs a lot of time to understand and troubleshoot the issue faced.

Mitigation:
1. We are currently using accelerometer (BMA280) in low power 2 mode with 0.5 ms of sleep duration. So, we can considering reducing the current consumption either by increasing the sleep duration or using the accelerometer in a mode with lesser current than low power 2 mode.
2. We will focus on referring more documents and articles on inductive charging to get the required energy requirements. If we are beyond the schedule and still not successful with inductive charging, then we will consider switching to an alternative power source such as USB charging.
3. To know how much data is enough/ less from the accelerometer, we have found out a simple solution to configure a simple app from the mobile (all mobiles have a accelerometer and a gyroscope).
We take the values of the mobile-accelerometer through a simple javascript application, populate the data to a csv-file/ populate the data in realtime to the algorithm we are generating. Thus before the firmware development we will have a clear idea on how much data would be required for acquisition.

4. We are trying to get a simpler lightweight Machine learning algorithm - which can run on a smartphone. If we cannot find the exact configuration we need, we will try dumping the data to any cloud platform to do the work for us - say AWS/IBM Watson etc..
5. Since it is considered as a prototype, even with a max delay to recognise the commands, the minimal success would be to achieve a command. Thus if the commands are recognised we can go ahead and start mitigating the delay.
6. We will focus on configuring only 1 or 2 devices with Bluetooth mesh network to make a simple network by referring documentations and receiving guidance from people who have worked on Bluetooth mesh network. If we are unable to achieve Bluetooth mesh network in the required time then we will consider using ZigBee/WiFi.

Accomplishments:
- We are on schedule for the project.
- We have recalculated the energy profile -current in each mode of operation and its functionality.
- We have completed parts selection for energy storage device and power management unit.
- We have re-calculated the peak current and the amount of energy that has to be supplied to the circuit from the battery.
- We have decided on unregulated power supply
- Worked on the Machine Learning Algorithms to see which would be a good fit for data extraction and prediction.

Next week:
- Schematics design for the circuit
- Energy spiked calculation
- Simulation of Voltage droop
- We need to work on Bluetooth Mesh
- Keep the work going on with the Algorithm for the Machine Learning

Reference:
http://www.lipolbattery.com/lithium%20polymer%20battery.htmlhttps://milliamps-watts.appspot.com/

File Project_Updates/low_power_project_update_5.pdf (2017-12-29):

### LOW POWER EMBEDDED DESIGN PROJECT UPDATE #5

Team Name: WearTech

Team Mates:

Sanjana Kalyanappagol | Shekhar Satyanarayana
saka2821@colorado.edu | shsa5563@colorado.edu

Executive Summary:

Part Selection
Battery | GMB401215-45mAh
PMU IC | LT1965
Processor | EFR32BG121 – f1024
Inductive Charging IC | BQ5103B
Battery Charger IC | BQ24040
Sensor | BMA280

As discussed, our project requires 2 Blue Gecko dev kits to act as devices in the mesh network.

On Schedule: Yes

Accomplishments:
- We have completed 70% of the schematics.
- Read about Bluetooth Mesh.
- Researched on features, components to be added to schematic to enable programming of your micro controller or SoC
- Work on the process of how to compile and download code to the board - the target board
- Investigated which signals will have test point
- Work on the Algorithm for the Machine Learning

Next week:
- Keep the work going in Schematics design for the circuit
- Start with the Layouts
- Energy spike calculation
- We need to work on Bluetooth Mesh
- Work on the Algorithm for the Machine Learning

### 1. What features, components, will need to be added to your schematic to enable

programming of your micro controller or SoC?
According to the https://www.silabs.com/documents/login/datasheets/efr32bg12-datasheet.pdf (https://www.silabs.com/documents/login/data-sheets/efr32bg12-datasheet.pdf) Datasheet :


2-Pin Serial-Wire debug interface is used by the EFR3BG12
But according to the https://www.silabs.com/documents/public/application-notes/an958-mcu-stk-wstk-guide.pdf (https://www.silabs.com/documents/public/application-notes/an958-mcu-stk-wstk-guide.pdf)


We can select any of the above interfaces. We have chosen 20-pin Standard ARM Cortex Debug+ETM connector.
References:
- https://www.silabs.com/documents/public/application-notes/AN0043.pdf
- http://www.digikey.pt/Web%20Export/Supplier%20Content/EnergyMicro_914/PDF/energy-micro-an-an0002.pdf (http://www.digikey.pt/Web%20Export/Supplier%20Content/EnergyMicro_914/PDF/energy-micro-an-an0002.pdf)
- https://www.silabs.com/documents/public/application-notes/an958-mcustk-wstk-guide.pdf (https://www.silabs.com/documents/public/application-notes/an958-mcu-stk-wstk-guide.pdf)


The Serial Wire (SWD) interface is supported by all EFM32 and EZR32 Wireless MCU Series 0 devices. The SWD debug interface consists of the SWCLK (clock input) and SWDIO (data in/out) lines, in addition to the optional SWO (serial wire output). The SWO line is used for instrumentation trace and program counter sampling, and is not needed for programming and normal debugging. However, it can be valuable in advanced debugging scenarios, and it is therefore recommended to include this line in a design. The connection to an ARM 20-pin debug connector is shown in the following figure. Pins with no connection should be left unconnected.
Note: The Vtarget connection is not for supplying power. The debugger uses Vtarget as a reference voltage for the debugger's level translators

### 2. Describe the process of how you will compile and download code to your

board, the target board
We will be using Simplicity Studio 4-version to develop the firmware code. The code will be compiled in the Simplicity Studio 4. The generated executable is dumped to the board with the Debug Interface.
1. Connect the appropriate pins for the debug Interface
2. Open Simplicity Studio (Assuming that the code is already done)
3. Connect the BlueGecko to the PC, Detect the Part-Number in the Simplicity studio.
4. Compile the code and flash the executable generated to the board.

### 3. Which signals will have test points?

SPI GPIO pins from BMA 280, i2c from all the PMUs, PMU – battery-MCU input-Accelerometer Input- Inductive IC output (To check the voltage)
In reference to the Question4 diagram, we will have signals at P1, at AC1 & AC2, at the USB adapter, at , at the Battery (pin 10 from bq24040), at the load.
At the SPI pins from BMA and the corresponding pins in MCU.

### 4. Provide alternative charging method of the energy source other than the

energy harvester

Inductive Charging:
Since we could not simulate the Inductive charging and the battery charger, we have shown our approach for the application/implementation of the Inductive charging:
Reference: http://www.ti.com/lit/ds/symlink/bq51013b.pdf


Note: P1& P2 from both the Figures are to be connected.
The | pin of BQ51013B controls the Q1 switch, the alternative energy source
is a USB/AC adapter connected to the Q1 switch. Depending on the | , the
energy source can be chosen from the USB/AC Adapter or from the Indutcive Charging IC.

### 5. Backup solution to charge the energy storage element in the event that the

Energy Harvester circuity is not functional
Our Energy Harvester is an Inductive charger, if not functional we can switch back to the USB/AC adapter charger.

### 6. What is the maximum charging current allowed by the PMU circuitry?

For BQ51013B:

For BQ24040:

### 7. What is the maximum charging current allowed by the energy storage unit?

The battery is a LiPo 45mAH battery. Nominal of 40mAH capacity.
The Rapid charge of 0.5C => 0.5*40mA = 20mA
The standard charge current of 0.2C => 0.2*40mA = 8mA
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

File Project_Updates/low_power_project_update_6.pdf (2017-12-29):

### LOW POWER EMBEDDED DESIGN PROJECT UPDATE #6

Team Name: WearTech

Team Mates:

Sanjana Kalyanappagol | Shekhar Satyanarayana
saka2821@colorado.edu | shsa5563@colorado.edu

Executive Summary:

Part Selection
Battery | GMB401215-45mAh
PMU IC | LT1965
Processor | EFR32BG13– f1024
Inductive Charging IC | BQ5103B
Battery Charger IC | BQ24040
Sensor | BMA280

As discussed, our project requires 2 Blue Gecko dev kits to act as devices in the mesh network.

On Schedule: Yes

Accomplishments:
- We have completed 90% of the schematics.
- Read about Bluetooth Mesh.
- Worked on the ESD diode

Next week:
- Complete Schematics & get reviewed
- Complete the Layouts
- Start Firmware Development
- Test Inductive charging

I/O Ports:
According to the Ckt Diagram:
We have,

### 1. USB input and Q1 Switch 2. Input from Inductive charging at AC1, AC2 3. IN pin BQ024040 4. OUT from pin BQ24040 to the Battery 5. OUT from pin BQ24040 to the MCU 6. INPUT VCC power to the BMA280 from the MCU
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

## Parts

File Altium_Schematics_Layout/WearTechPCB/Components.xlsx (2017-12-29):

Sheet: Sheet1
MICRO USB |  | https://www.digikey.com/product-detail/en/amphenol-fci/10118192-0001LF/609-4613-1-ND/2785378
Coil | Dexerials : NSTC4832T7346-16B | COIL AND BATTERY NEED TO BE A SEPARATE ORDER : NOT IN DIGIKEY
ESD diode |  | https://www.digikey.com/product-detail/en/SMF05CT1G/SMF05CT1GOSCT-ND/1967287
C1 | 1uF at 5V | https://www.digikey.com/product-detail/en/kemet/C0603C105K9PACTU/399-7848-1-ND/3471571
C2/C14 | 22nF at 25V rating ;WV : 5v | https://www.digikey.com/product-detail/en/samsung-electro-mechanics/CL10B223KA8NNWC/1276-2000-1-ND/3890086
C4/C13 | 10nF at 25V rating ; WV : 5v | https://www.digikey.com/product-detail/en/samsung-electro-mechanics/CL10B103KA8NNNC/1276-1132-1-ND/3889218
C15/C16 | 0.47 at 25V rating; WV: 5v | https://www.digikey.com/product-detail/en/murata-electronics-north-america/GRM188R71E474KA12D/490-3291-1-ND/702832
C7 | 2.2nF at 25V rating ;WV : 5v | https://www.digikey.com/product-detail/en/kemet/C0603C222K3RACTU/399-9040-1-ND/3522557
C8 | 100nF at 25V rating; WV: 5v | https://www.digikey.com/product-detail/en/kemet/C0603C104K3RACTU/399-1281-1-ND/416057
C5 | 68nF at 25V rating ; WV:5v | https://www.digikey.com/product-detail/en/murata-electronics-north-america/GRM188R71E683KA01D/490-1523-1-ND/587864
C6 | 47nF at 25v | https://www.digikey.com/product-detail/en/samsung-electro-mechanics/CL10B473KA8NFNC/1276-2072-1-ND/3890158
C9 | 39nF at 25v | https://www.digikey.com/product-detail/en/kemet/C0603C393K3RACTU/399-7914-1-ND/3471637
C10/C12 | 10uF at 16v | https://www.digikey.com/product-detail/en/murata-electronics-north-america/GRM188R61C106KAALD/490-10728-1-ND/5251372
C11 | 0.1uF at 16v | https://www.digikey.com/product-detail/en/avx-corporation/0603YC104JAT2A/478-3726-1-ND/1116424
C36 | 0.1uF at 5v | https://www.digikey.com/product-detail/en/murata-electronics-north-america/GRM188R70J104KA01D/490-9730-1-ND/4934899
C3 | 10uF at 5v | https://www.digikey.com/product-detail/en/murata-electronics-north-america/GRM188R60J106ME47D/490-3896-1-ND/965938
C17/C18/C33/C24/C22/C20 | 0.1 Uf at 2.5 V | https://www.digikey.com/product-detail/en/murata-electronics-north-america/GRM188R71C104KA01D/490-1532-1-ND/587771
C21/C23/C28 | 10 uF at 2.5V | https://www.digikey.com/product-detail/en/samsung-electro-mechanics/CL10A226MR8NQNC/1276-1891-1-ND/3889977
C19 | 1uF at 2.5V | https://www.digikey.com/product-detail/en/samsung-electro-mechanics/CL10A105KA5LNNC/1276-1858-1-ND/3889944
C25/C29 | 220 nF at 2.5 V | https://www.digikey.com/product-detail/en/murata-electronics-north-america/GRM188R61A224KA01D/490-1537-1-ND/587776
C26/C30 | 10 pF at 2.5V | https://www.digikey.com/product-detail/en/murata-electronics-north-america/GRM1885C1H100JA01D/490-1403-1-ND/587642
C27 | 10 nF at 2.5 V | https://www.digikey.com/product-detail/en/murata-electronics-north-america/GRM1857U1A103JA44D/490-8269-1-ND/4380563
C31 | 2 pF at 2.5V | https://www.digikey.com/product-detail/en/samsung-electro-mechanics/CL10C020BB8NNNC/1276-1815-2-ND/3887473
C32 | 1 pF at 2.5V | https://www.digikey.com/product-detail/en/murata-electronics-north-america/GRM1885C1H1R0WA01D/490-16342-1-ND/7363324
NTC,R6,R11 | 10K | https://www.digikey.com/product-detail/en/yageo/RC0603JR-0710KL/311-10KGRCT-ND/729647
R8 | 66 | https://www.digikey.com/product-detail/en/yageo/RC0603FR-0766R5L/311-66.5HRCT-ND/730294
R9 | 196 | https://www.digikey.com/product-detail/en/yageo/RC0603FR-07196RL/311-196HRCT-ND/729953
R7/R2/R1 | 1.5K | https://www.digikey.com/product-detail/en/yageo/RC0603JR-071K5L/311-1.5KGRCT-ND/729636
Oscillator - Y2 | 32.768 | https://www.digikey.com/product-detail/en/txc-corporation/9HT10-32.768KDZF-T/887-1504-1-ND/2690372
Oscillator - Y1 | 38.4 | https://www.digikey.com/products/en?keywords=1253-1777-1-ND
P2
R10 | 1 ohm | https://www.digikey.com/product-detail/en/yageo/RC0603FR-071RL/311-1.00HRCT-ND/729789
R12 | 0 ohm | https://www.digikey.com/product-detail/en/yageo/RC0603JR-070RL/311-0.0GRCT-ND/729622
L4 |  | https://www.digikey.com/product-detail/en/murata-electronics-north-america/LQW18AN3N0C80D/490-11771-1-ND/5333611
L3 |  | https://www.digikey.com/product-detail/en/murata-electronics-north-america/LQP18MN1N8C02D/490-11750-1-ND/5333590
L2- Ferrite Bead |  | https://www.digikey.com/product-detail/en/wurth-electronics-inc/74279266/732-4484-1-ND/3907313
Antenna Connector- J24 |  | https://www.digikey.com/product-detail/en/molex-llc/0734120110/WM5587CT-ND/1894612
Antenna |  | https://www.digikey.com/product-detail/en/siretta-ltd/ECHO18-0.1M-UFL-S-S-15/ECHO18-0.1M-UFL-S-S-15-ND/6096325
Debug Header
Switch | tps1120 | https://www.digikey.com/products/en/discrete-semiconductor-products/transistors-fets-mosfets-arrays/289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

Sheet: Sheet2
Header | HDR1X3 | https://www.digikey.com/product-detail/en/wurth-electronics-inc/61300311121/732-5316-ND/4846825
D1/D2/D4 |  | https://www.digikey.com/product-detail/en/osram-opto-semiconductors-inc/LO-L29K-H2K1-24-Z/475-2740-1-ND/1938907
Cout | 10uF at 3.6v | https://www.digikey.com/product-detail/en/avx-corporation/06034D106MAT2A/478-5718-1-ND/2136326
Cin | 10uF at 5V | https://www.digikey.com/product-detail/en/murata-electronics-north-america/GRM188R60J106ME47D/490-3896-1-ND/965938
C34 | 10uF at 4v | https://www.digikey.com/product-detail/en/avx-corporation/06034D106MAT2A/478-5718-1-ND/2136326
C35 | 10uF at 2.5v | https://www.digikey.com/products/en/capacitors/ceramic-capacitors/60?k=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
R4 | 12K | https://www.digikey.com/product-detail/en/yageo/RC0603JR-0712KL/311-12KGRCT-ND/729656
R5 | 2K | https://www.digikey.com/product-detail/en/panasonic-electronic-components/ERJ-3EKF2001V/P2.00KHCT-ND/198219
R3 | 250K | https://www.digikey.com/product-detail/en/yageo/RC0402JR-0710KL/311-10KJRTR-ND/726418
LT1965 |  | https://www.digikey.com/product-detail/en/linear-technology/LT1965IDD-2.5-PBF/LT1965IDD-2.5-PBF-ND/2107616
JUST ONE ORDER:
BQ51013B | https://www.digikey.com/product-detail/en/texas-instruments/BQ51013BRHLR/296-38885-1-ND/5142996
BQ24040 | https://www.digikey.com/products/en/integrated-circuits-ics/pmic-battery-chargers/781?k=BQ24040DSQT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
BMA280 | https://www.digikey.com/products/en/sensors-transducers/motion-sensors-accelerometers/515?k=BMA280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
EFR32BG | https://www.digikey.com/products/en/rf-if-and-rfid/rf-transceiver-ics/879?k=EFR32BG13P732F512GM48-C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

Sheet: Sheet3
ALL TWO COMPONENTS
Coil | https://www.digikey.com/product-detail/en/vishay-dale/IWAS3827ECEB100J50/541-1695-ND/3641244
Capacitor C8 | https://www.digikey.com/product-detail/en/kemet/C0603C101J3GACTU/399-8980-1-ND/3522497
Resistor R4 for 40mAH | https://www.digikey.com/product-detail/en/yageo/RC0603JR-0713KL/311-13KGRCT-ND/729660

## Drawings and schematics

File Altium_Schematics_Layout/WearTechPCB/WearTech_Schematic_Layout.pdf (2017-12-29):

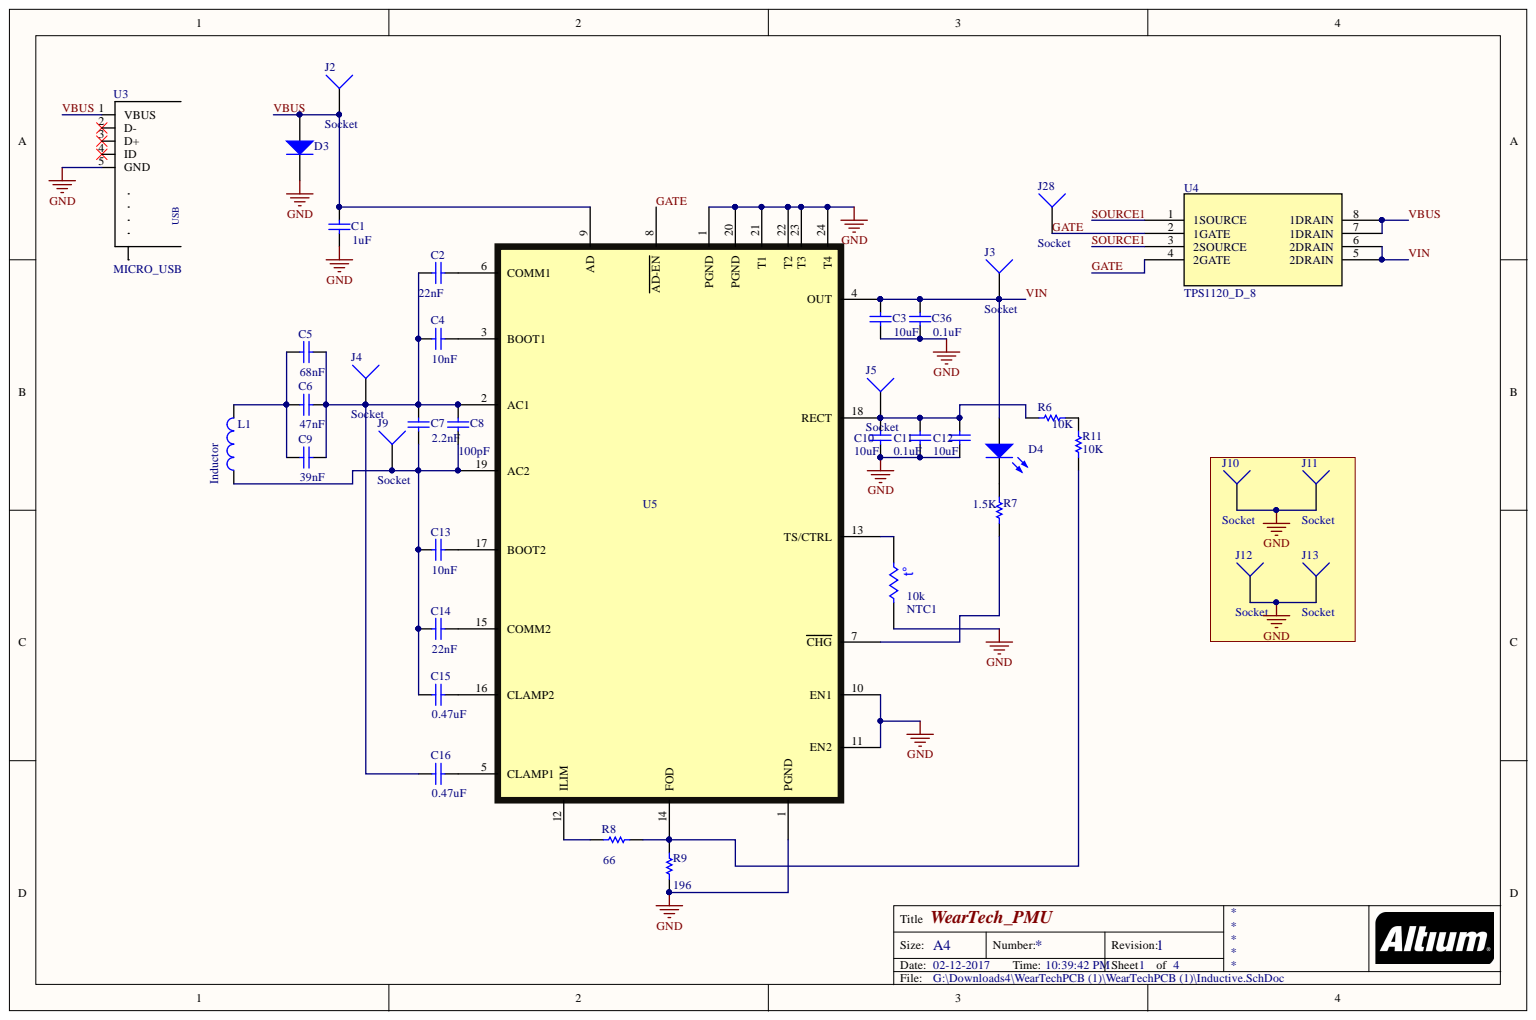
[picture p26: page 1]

T i t l e WearTech_PM | **** *

Size: A4 | N umber: | Rev i s i o n : 1
Date: T ime: : 2 PM | | Sheet f

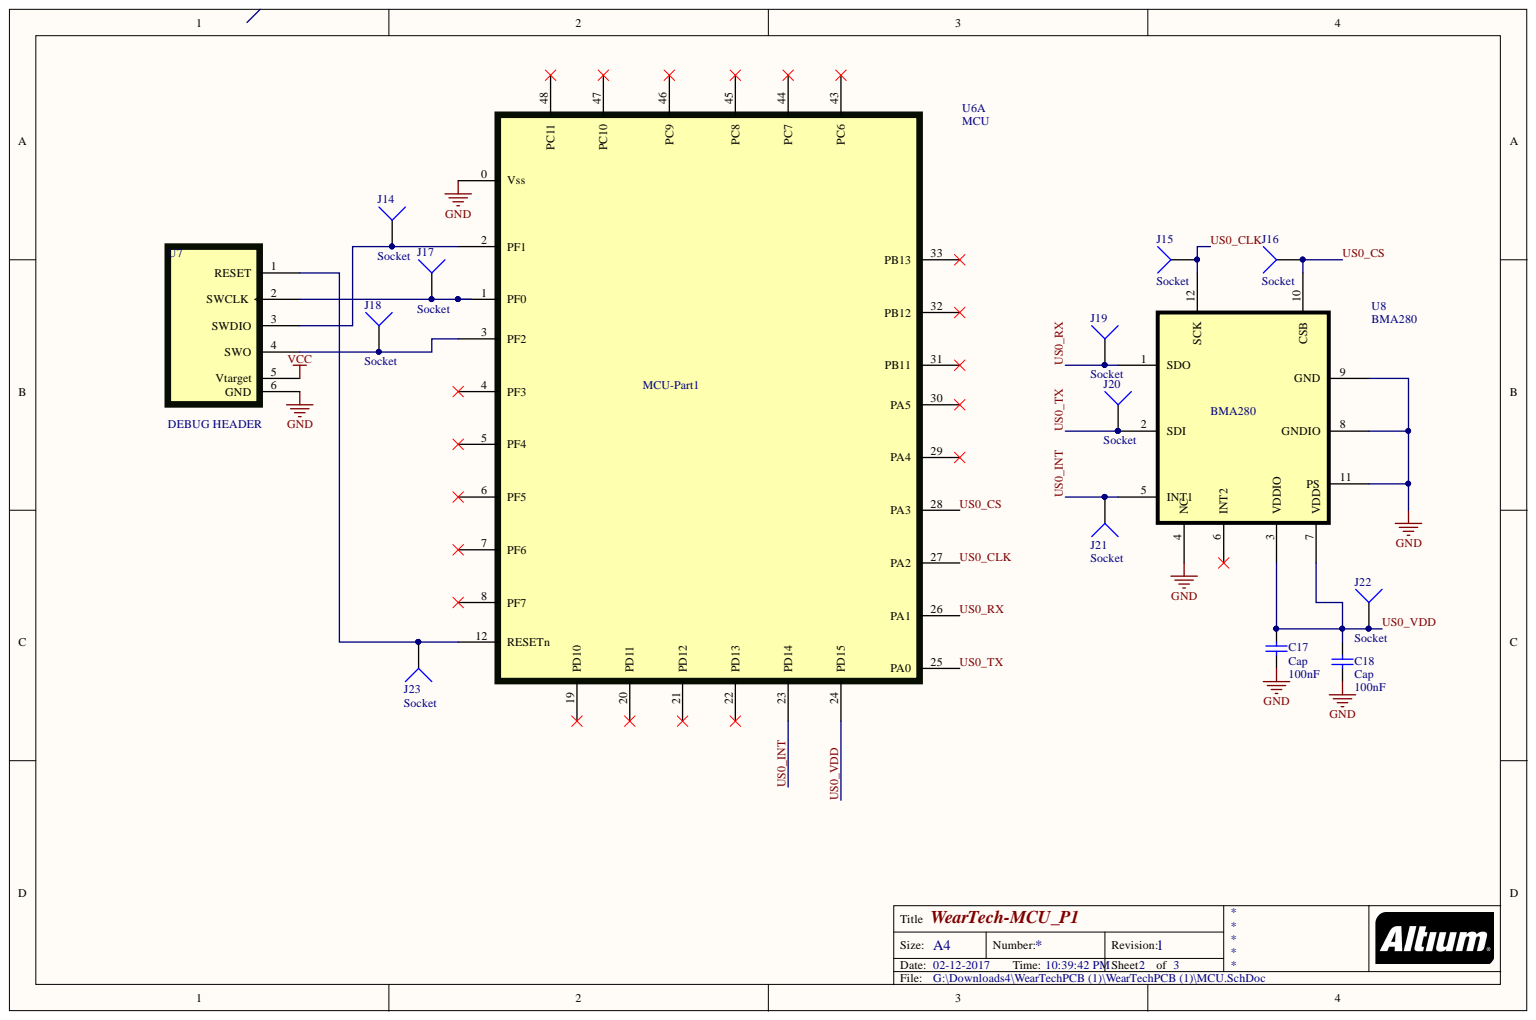
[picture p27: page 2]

3 | J 1 8 Socket | 3

Size: A4 | N umber: | Rev i s i o n : 1

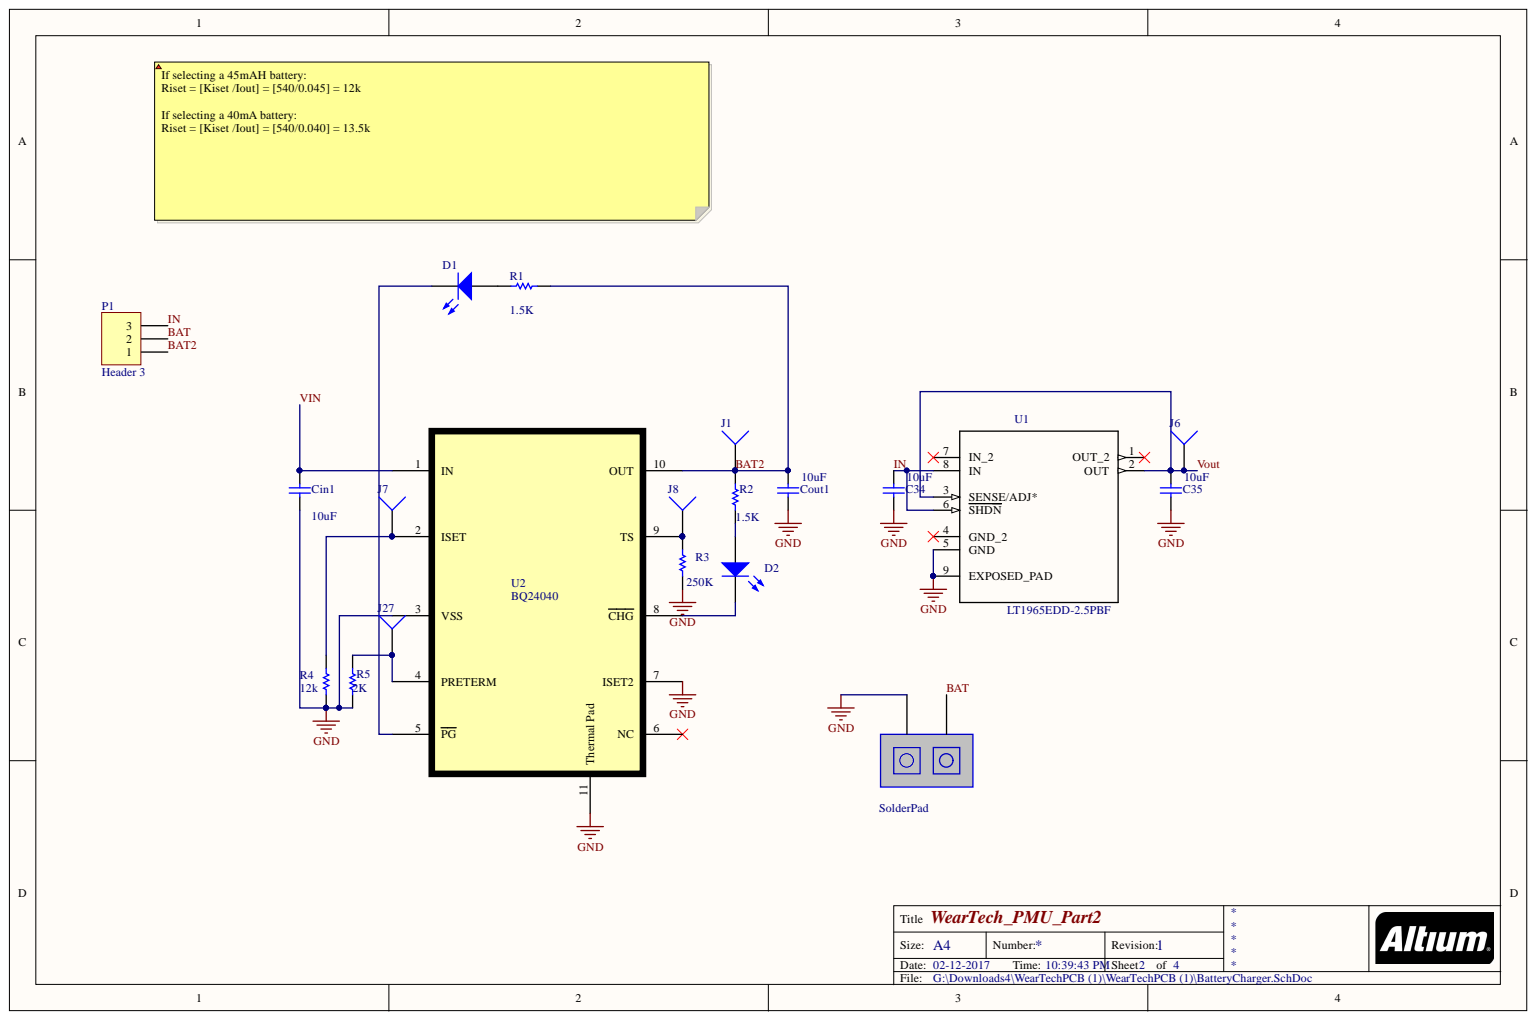
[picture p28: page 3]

J 7 | T S 4 0 CH G ISE T 2 N C | u F 4 | 3

6 | SE SH D N G N D _ 2 G N D E XPOSE D _ PA D

R5
2 K | 5

T i t l e WearTech_PM | ****

Size: A4 | N umber: | Rev i s i o n : 1

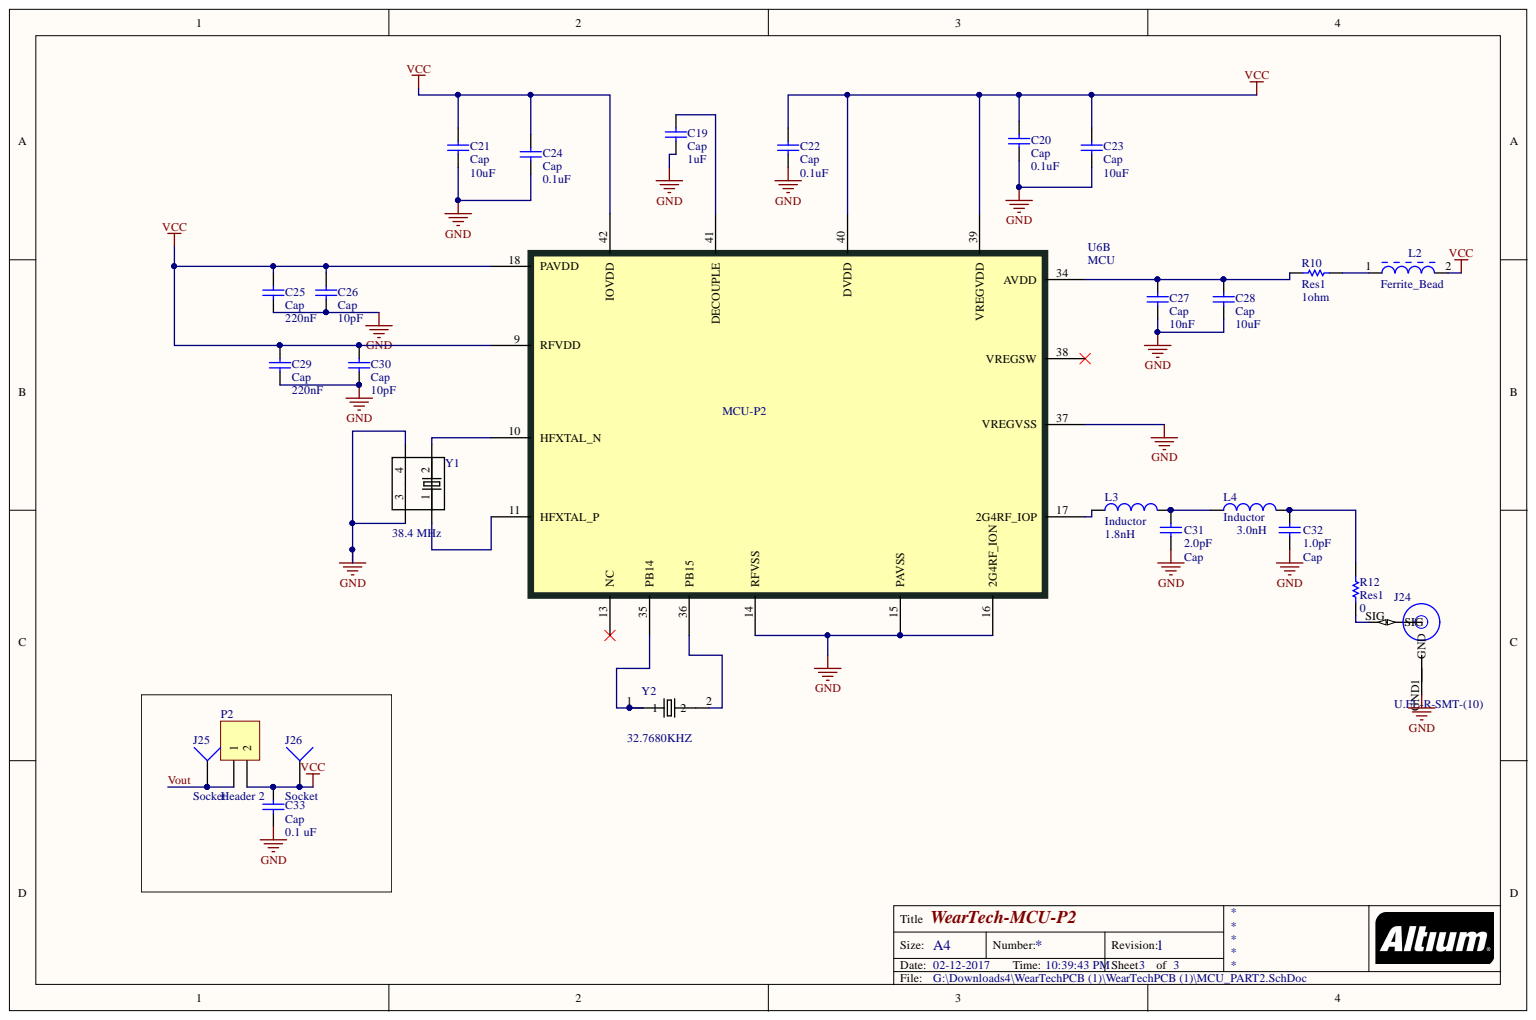
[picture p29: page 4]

Size: A4 | N umber: | Rev i s i o n : 1

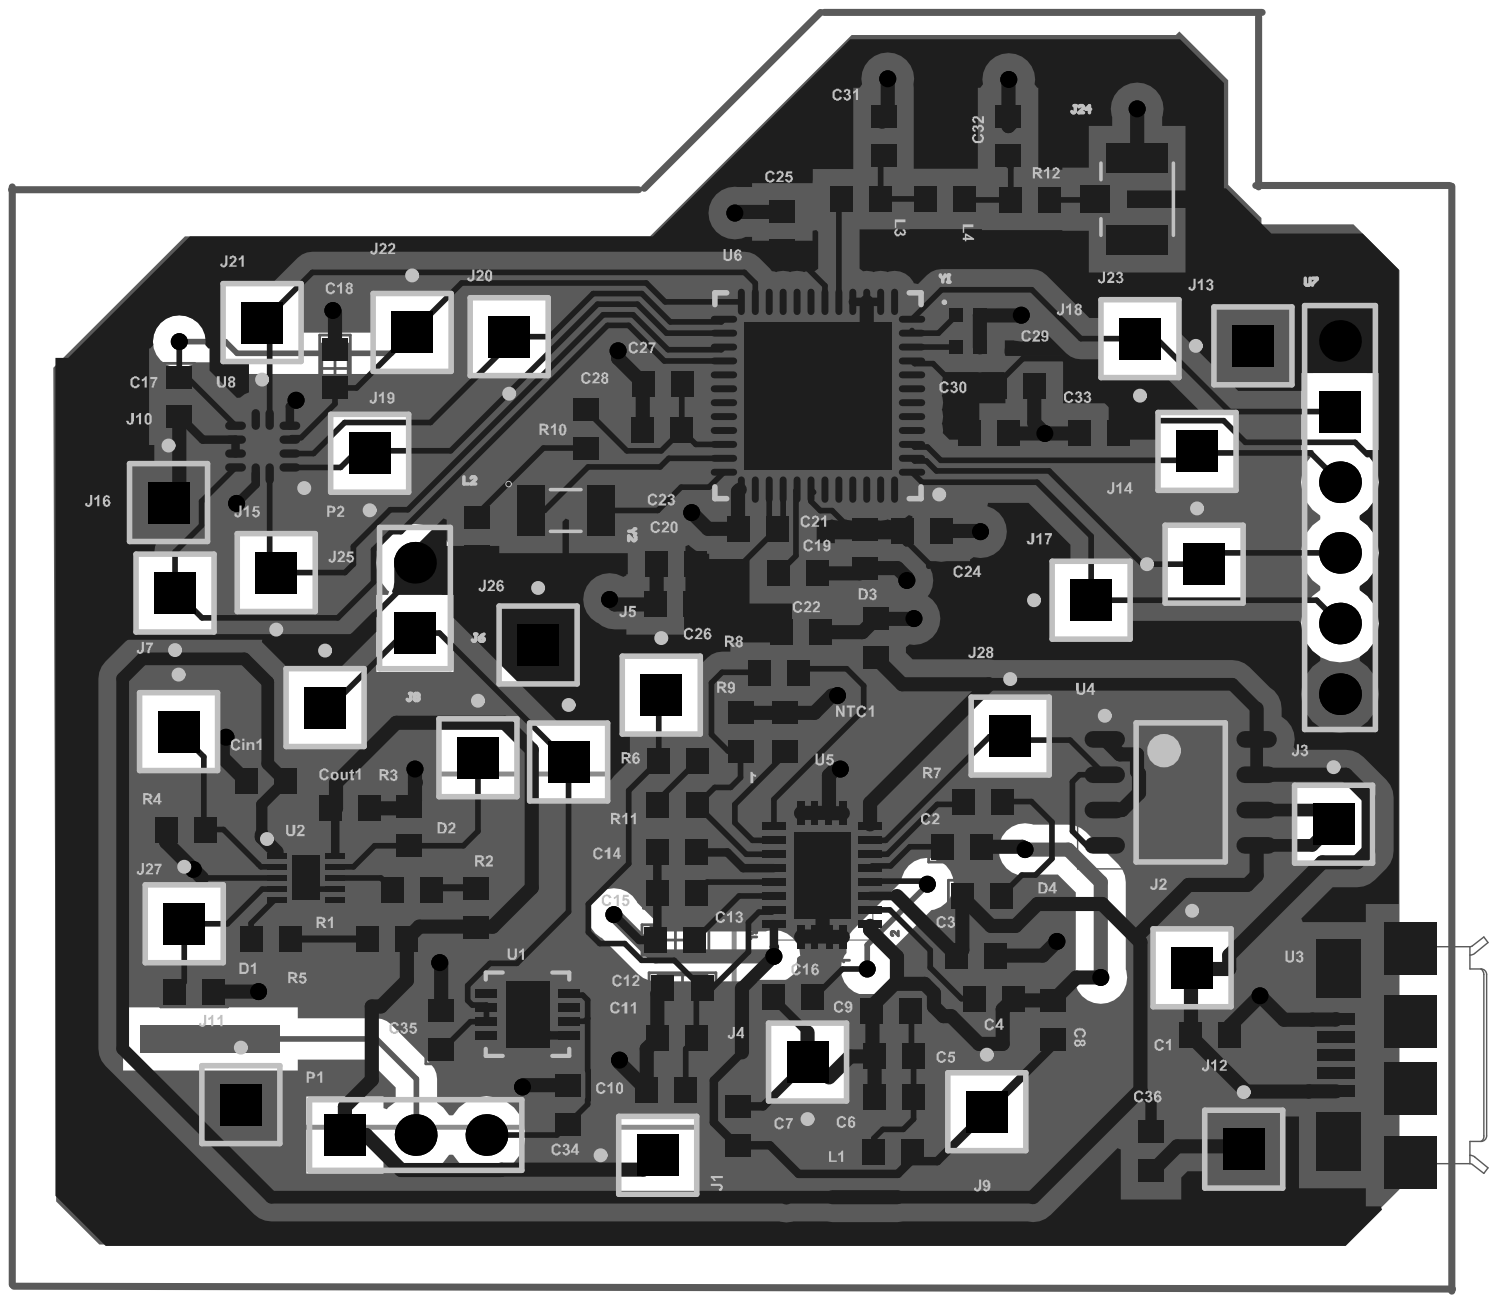
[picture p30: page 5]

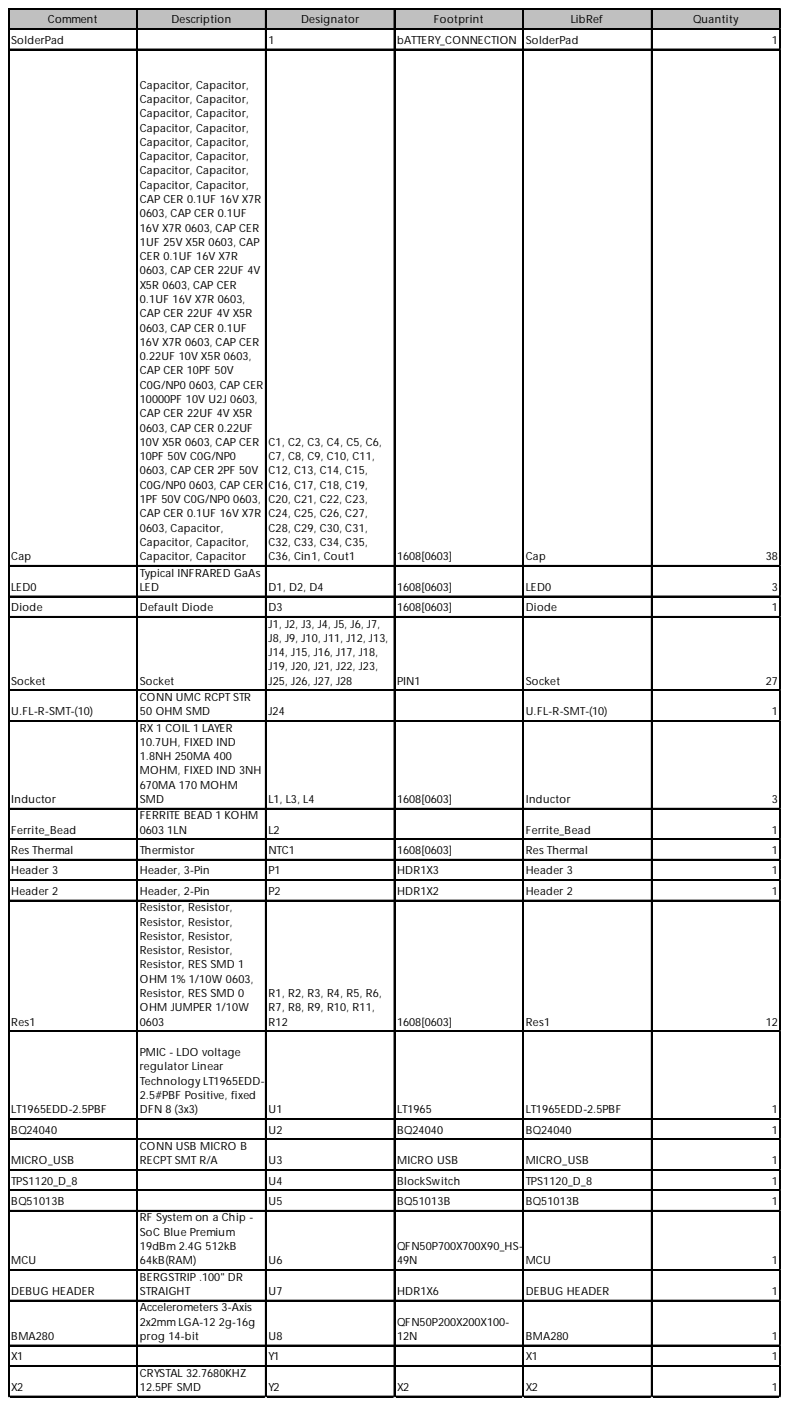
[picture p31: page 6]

Comment | Description | Designator | Footprint | LibRef | Quantity

SolderPad | | 1 | bATTERY_CONNECTION | SolderPad | 1

LED0 | Typical INFRARED GaAs LED | D1, D2, D4 | 1608[0603] | LED0 | 3

Diode | Default Diode | D3 | 1608[0603] | Diode | 1
Socket | Socket | J1, J2, J3, J4, J5, J6, J7, J8, J9, J10, J11, J12, J13, J14, J15, J16, J17, J18, J19, J20, J21, J22, J23, J25, J26, J27, J28 | PIN1 | Socket | 27

U.FL-R-SMT-(10) | CONN UMC RCPT STR 50 OHM SMD | J24 | | U.FL-R-SMT-(10) | 1

Inductor | RX 1 COIL 1 LAYER 10.7UH, FIXED IND 1.8NH 250MA 400 MOHM, FIXED IND 3NH 670MA 170 MOHM SMD | L1, L3, L4 | 1608[0603] | Inductor | 3

Ferrite_Bead | FERRITE BEAD 1 KOHM 0603 1LN | L2 | | Ferrite_Bead | 1

Res Thermal | Thermistor | NTC1 | 1608[0603] | Res Thermal | 1

Header 3 | Header, 3-Pin | P1 | HDR1X3 | Header 3 | 1

Header 2 | Header, 2-Pin | P2 | HDR1X2 | Header 2 | 1
Res1 | Resistor, Resistor, Resistor, Resistor, Resistor, Resistor, Resistor, Resistor, Resistor, RES SMD 1 OHM 1% 1/10W 0603, Resistor, RES SMD 0 OHM JUMPER 1/10W 0603 | R1, R2, R3, R4, R5, R6, R7, R8, R9, R10, R11, R12 | 1608[0603] | Res1 | 12

LT1965EDD-2.5PBF | PMIC - LDO voltage regulator Linear Technology LT1965EDD-2.5#PBF Positive, fixed DFN 8 (3x3) | U1 | LT1965 | LT1965EDD-2.5PBF | 1

BQ24040 | | U2 | BQ24040 | BQ24040 | 1
MICRO_USB | CONN USB MICRO B RECPT SMT R/A | U3 | MICRO USB | MICRO_USB | 1

TPS1120_D_8 | | U4 | BlockSwitch | TPS1120_D_8 | 1

BQ51013B | | U5 | BQ51013B | BQ51013B | 1
MCU | RF System on a Chip -SoC Blue Premium 19dBm 2.4G 512kB 64kB(RAM) | U6 | QFN50P700X700X90_HS-49N | MCU | 1

DEBUG HEADER | BERGSTRIP .100" DR STRAIGHT | U7 | HDR1X6 | DEBUG HEADER | 1

BMA280 | Accelerometers 3-Axis 2x2mm LGA-12 2g-16g prog 14-bit | U8 | QFN50P200X200X100-12N | BMA280 | 1

X1 | | Y1 | | X1 | 1
X2 | CRYSTAL 32.7680KHZ 12.5PF SMD | Y2 | X2 | X2 | 1

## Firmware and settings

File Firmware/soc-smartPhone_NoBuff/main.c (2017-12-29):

/***********************************************************************************************//**
 * \file   main.c
 * \brief  Silabs HTM IAS and Beaconing Demo Application
 *         This application is intended to be used with the iOS Silicon Labs
 *         app for demonstration purposes
 ***************************************************************************************************
 * <b> (C) Copyright 2015 Silicon Labs, http://www.silabs.com</b>
 ***************************************************************************************************
 * This file is licensed under the Silabs License Agreement. See the file
 * "Silabs_License_Agreement.txt" for details. Before using this software for
 * any purpose, you must agree to the terms of that agreement.
 **************************************************************************************************/

#include "init_mcu.h"
#include "init_board.h"
#include "init_app.h"
#include "boards.h"
#include "ble-configuration.h"
#include "board_features.h"

/* BG stack headers */
#include "bg_types.h"
#include "native_gecko.h"
#include "gatt_db.h"
#include "aat.h"

/* application specific files */
#include "app.h"

/* libraries containing default gecko configuration values */
#include "em_emu.h"
#include "em_cmu.h"

/* Device initialization header */
#include "hal-config.h"

/* BG stack headers */
#include "bg_types.h"
#include "native_gecko.h"

/* profiles */
#include "htm.h"
#include "ia.h"

/* BG stack headers*/
#include "gatt_db.h"

/* em library */
#include "em_system.h"

/* application specific headers */
#include "app_ui.h"
#include "app_hw.h"
#include "advertisement.h"
#include "beacon.h"
#include "app_timer.h"
#include "board_features.h"


#include "spi.h"
#include "bma280.h"


/* Own header */
#include "app.h"

#if defined(HAL_CONFIG)
#include "bsphalconfig.h"
#else
#include "bspconfig.h"
#endif

#include "bsp.h"

#include "gpio.h"
#include "bma280.h"
#include "spi.h"
#include "letimer0.h"
#include "cmu.h"
#include "udelay.h"


#define INT_MAP_0_Reg 0x19
/***************************************************************************************************
 * Static Function Declarations
 **************************************************************************************************/
   #ifndef FEATURE_IOEXPANDER
/* Periodically called Display Polarity Inverter Function for the LCD.
   Toggles the the EXTCOMIN signal of the Sharp memory LCD panel, which prevents building up a DC
   bias according to the LCD's datasheet */
static void (*dispPolarityInvert)(void *);
  #endif /* FEATURE_IOEXPANDER */
/***********************************************************************************************//**
 * @addtogroup Application
 * @{
 **************************************************************************************************/

/***********************************************************************************************//**
 * @addtogroup app
 * @{
 **************************************************************************************************/

#ifndef MAX_CONNECTIONS
#define MAX_CONNECTIONS 4
#endif
uint8_t bluetooth_stack_heap[DEFAULT_BLUETOOTH_HEAP(MAX_CONNECTIONS)];

// Gecko configuration parameters (see gecko_configuration.h)
static const gecko_configuration_t config = {
  .config_flags = 0,
  .sleep.flags = SLEEP_FLAGS_DEEP_SLEEP_ENABLE,
  .bluetooth.max_connections = MAX_CONNECTIONS,
  .bluetooth.heap = bluetooth_stack_heap,
  .bluetooth.heap_size = sizeof(bluetooth_stack_heap),
  .bluetooth.sleep_clock_accuracy = 100, // ppm
  .gattdb = &bg_gattdb_data,
  .ota.flags = 0,
  .ota.device_name_len = 3,
  .ota.device_name_ptr = "OTA",
#if (HAL_PA_ENABLE) && defined(FEATURE_PA_HIGH_POWER)
  .pa.config_enable = 1, // Enable high power PA
  .pa.input = GECKO_RADIO_PA_INPUT_VBAT, // Configure PA input to VBAT
#endif // (HAL_PA_ENABLE) && defined(FEATURE_PA_HIGH_POWER)
};

/**
 * button initialization. Configure pushbuttons PB0,PB1
 * as inputs.
 */
static void button_init()
{
	// Configure pin as input
	  GPIO_PinModeSet(BSP_BUTTON0_PORT, BSP_BUTTON0_PIN, gpioModeInput, 1);
	  // Configure pin as input
	  GPIO_PinModeSet(BSP_BUTTON1_PORT, BSP_BUTTON1_PIN, gpioModeInput, 1);
}

/**
 * LED initialization. Configure LED pins as outputs
 */
static void led_init()
{
  // configure LED0 and LED1 as outputs
  GPIO_PinModeSet(BSP_LED0_PORT, BSP_LED0_PIN, gpioModePushPull, 0);
  GPIO_PinModeSet(BSP_LED0_PORT, BSP_LED0_PIN, gpioModePushPull, 0);
}

/**************************************************************************//**
 * @brief   Register a callback function at the given frequency.
 *
 * @param[in] pFunction  Pointer to function that should be called at the
 *                       given frequency.
 * @param[in] argument   Argument to be given to the function.
 * @param[in] frequency  Frequency at which to call function at.
 *
 * @return  0 for successful or
 *         -1 if the requested frequency does not match the RTC frequency.
 *****************************************************************************/
int rtcIntCallbackRegister(void (*pFunction)(void*),
                           void* argument,
                           unsigned int frequency)
{
  #ifndef FEATURE_IOEXPANDER

  dispPolarityInvert =  pFunction;
  /* Start timer with required frequency */
  gecko_cmd_hardware_set_soft_timer(TIMER_MS_2_TIMERTICK(1000 / frequency), DISP_POL_INV_TIMER, false);

  #endif /* FEATURE_IOEXPANDER */

  return 0;
}

void main(void)
{
//  // Initialize device
//  initMcu();
//  // Initialize board
//  initBoard();
//  // Initialize application
//  initApp();
//
//  // Initialize LEDs
//  BSP_LedsInit();
//
//#ifndef FEATURE_LED_BUTTON_ON_SAME_PIN
//  // Configure pin as input
//  GPIO_PinModeSet(BSP_BUTTON0_PORT, BSP_BUTTON0_PIN, gpioModeInput, 1);
//  // Configure pin as input
//  GPIO_PinModeSet(BSP_BUTTON1_PORT, BSP_BUTTON1_PIN, gpioModeInput, 1);
//#endif

#ifdef FEATURE_SPI_FLASH
	  /* Put the SPI flash into Deep Power Down mode for those radio boards where it is available */
	  MX25_init();
	  MX25_DP();
	  /* We must disable SPI communication */
	  USART_Reset(USART1);

	#endif /* FEATURE_SPI_FLASH */

	  /* Initialize peripherals */
	  enter_DefaultMode_from_RESET();

  // Initialize stack
  gecko_init(&config);

  /* Initialize clocks */
   cmu_init();

   gpio_init();

   LETIMER0_call(2);

   /* Initialize SPI */
   spi_init();

   /* Enable BMA280 in SUSPEND mode */
 //  BMA280_Enable();
      led_init();
     button_init();

     //LCD_init();

   /* Initialize GPIO interrupt */
   gpio_interrupt_int();

   /* Start GPIO interrupt */
   GPIO_IntEnable(GPIO_INT_ENABLE);

   BMA280_Enable();

  while (1) {
	//BMA280_Enable();
    struct gecko_cmd_packet* evt;
    // Check for stack event.
    evt = gecko_wait_event();
    // Run application and event handler.
    /* Flag for indicating DFU Reset must be performed */
      static uint8_t boot_to_dfu = 0;
      //BMA280_RegisterRead(USART1,INT_MAP_0_Reg);

      switch (BGLIB_MSG_ID(evt->header)) {
        /* Boot event and connection closed event */
        case gecko_evt_system_boot_id:
        case gecko_evt_le_connection_closed_id:

          /* Initialize app */
          appInit(); /* App initialization */
         // BMA280_RegisterRead(USART1,INT_MAP_0_Reg);
          htmInit(); /* Health thermometer initialization */
          //BMA280_RegisterRead(USART1,INT_MAP_0_Reg);
          advSetup(); /* Advertisement initialization */
          //BMA280_RegisterRead(USART1,INT_MAP_0_Reg);

          /* Enter to DFU OTA mode if needed */
          if (boot_to_dfu) {
            gecko_cmd_system_reset(2);
          }

          break;

        /* Connection opened event */
        case gecko_evt_le_connection_opened_id:
          /* Call advertisement.c connection started callback */
          advConnectionStarted();
          //BMA280_RegisterRead(USART1,INT_MAP_0_Reg);
          break;

        /* Value of attribute changed from the local database by remote GATT client */
        case gecko_evt_gatt_server_attribute_value_id:
          /* Check if changed characteristic is the Immediate Alert level */
          if ( gattdb_alert_level == evt->data.evt_gatt_server_attribute_value.attribute) {
            /* Write the Immediate Alert level value */
            iaImmediateAlertWrite(&evt->data.evt_gatt_server_attribute_value.value);
            //BMA280_RegisterRead(USART1,INT_MAP_0_Reg);
          }
          break;

        /* Indicates the changed value of CCC or received characteristic confirmation */
        case gecko_evt_gatt_server_characteristic_status_id:
          /* Check if changed client char config is for the temperature measurement */
          if ((gattdb_temp_measurement == evt->data.evt_gatt_server_attribute_value.attribute)
              && (evt->data.evt_gatt_server_characteristic_status.status_flags == 0x01)) {
            /* Call HTM temperature characteristic status changed callback */
            htmTemperatureCharStatusChange(
              evt->data.evt_gatt_server_characteristic_status.connection,
              evt->data.evt_gatt_server_characteristic_status.client_config_flags);
          }
          break;

        /* Software Timer event */
        case gecko_evt_hardware_soft_timer_id:
          /* Check which software timer handle is in question */

          switch (evt->data.evt_hardware_soft_timer.handle) {
            case UI_TIMER: /* App UI Timer (LEDs, Buttons) */
              appUiTick();
              break;
            case ADV_TIMER: /* Advertisement Timer */
              advSetup();
              break;
            case TEMP_TIMER: /* Temperature measurement timer */
              /* Make a temperature measurement */
              htmTemperatureMeasure();
              break;
//            #ifndef FEATURE_IOEXPANDER
//            case DISP_POL_INV_TIMER:
//              /*Toggle the the EXTCOMIN signal, which prevents building up a DC bias  within the
//               * Sharp memory LCD panel */
//              dispPolarityInvert(0);
//              break;
//            #endif /* FEATURE_IOEXPANDER */
            default:
              break;
          }
          break;

        /* User write request event. Checks if the user-type OTA Control Characteristic was written.
         * If written, boots the device into Device Firmware Upgrade (DFU) mode. */
        case gecko_evt_gatt_server_user_write_request_id:
          /* Handle OTA */
          if (evt->data.evt_gatt_server_user_write_request.characteristic == gattdb_ota_control) {
            /* Set flag to enter to OTA mode */
            boot_to_dfu = 1;
            /* Send response to Write Request */
            gecko_cmd_gatt_server_send_user_write_response(
              evt->data.evt_gatt_server_user_write_request.connection,
              gattdb_ota_control,
              bg_err_success);

            /* Close connection to enter to DFU OTA mode */
            gecko_cmd_endpoint_close(evt->data.evt_gatt_server_user_write_request.connection);
          }
          break;

        default:
        	//BMA280_RegisterRead(USART1,INT_MAP_0_Reg);
          break;
      }
   // appHandleEvents(evt);
    //BMA280_Enable();
  }
}

/** @} (end addtogroup app) */
/** @} (end addtogroup Application) */

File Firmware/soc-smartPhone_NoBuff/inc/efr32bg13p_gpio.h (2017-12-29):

/**************************************************************************//**
 * @file efr32bg13p_gpio.h
 * @brief EFR32BG13P_GPIO register and bit field definitions
 * @version 5.3.2
 ******************************************************************************
 * # License
 * <b>Copyright 2017 Silicon Laboratories, Inc. http://www.silabs.com</b>
 ******************************************************************************
 *
 * Permission is granted to anyone to use this software for any purpose,
 * including commercial applications, and to alter it and redistribute it
 * freely, subject to the following restrictions:
 *
 * 1. The origin of this software must not be misrepresented; you must not
 *    claim that you wrote the original software.@n
 * 2. Altered source versions must be plainly marked as such, and must not be
 *    misrepresented as being the original software.@n
 * 3. This notice may not be removed or altered from any source distribution.
 *
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
 * Silicon Laboratories, Inc. will not be liable for any consequential,
 * incidental, or special damages, or any other relief, or for any claim by
 * any third party, arising from your use of this Software.
 *
 *****************************************************************************/

#if defined(__ICCARM__)
#pragma system_include       /* Treat file as system include file. */
#elif defined(__ARMCC_VERSION) && (__ARMCC_VERSION >= 6010050)
#pragma clang system_header  /* Treat file as system include file. */
#endif

/**************************************************************************//**
* @addtogroup Parts
* @{
******************************************************************************/
/**************************************************************************//**
 * @defgroup EFR32BG13P_GPIO GPIO
 * @{
 * @brief EFR32BG13P_GPIO Register Declaration
 *****************************************************************************/
/** GPIO Register Declaration */
typedef struct {
  GPIO_P_TypeDef P[12];          /**< Port configuration bits */

  uint32_t       RESERVED0[112]; /**< Reserved for future use **/
  __IOM uint32_t EXTIPSELL;      /**< External Interrupt Port Select Low Register  */
  __IOM uint32_t EXTIPSELH;      /**< External Interrupt Port Select High Register  */
  __IOM uint32_t EXTIPINSELL;    /**< External Interrupt Pin Select Low Register  */
  __IOM uint32_t EXTIPINSELH;    /**< External Interrupt Pin Select High Register  */
  __IOM uint32_t EXTIRISE;       /**< External Interrupt Rising Edge Trigger Register  */
  __IOM uint32_t EXTIFALL;       /**< External Interrupt Falling Edge Trigger Register  */
  __IOM uint32_t EXTILEVEL;      /**< External Interrupt Level Register  */
  __IM uint32_t  IF;             /**< Interrupt Flag Register  */
  __IOM uint32_t IFS;            /**< Interrupt Flag Set Register  */
  __IOM uint32_t IFC;            /**< Interrupt Flag Clear Register  */
  __IOM uint32_t IEN;            /**< Interrupt Enable Register  */
  __IOM uint32_t EM4WUEN;        /**< EM4 wake up Enable Register  */

  uint32_t       RESERVED1[4];   /**< Reserved for future use **/
  __IOM uint32_t ROUTEPEN;       /**< I/O Routing Pin Enable Register  */
  __IOM uint32_t ROUTELOC0;      /**< I/O Routing Location Register  */
  __IOM uint32_t ROUTELOC1;      /**< I/O Routing Location Register 1  */

  uint32_t       RESERVED2[1];   /**< Reserved for future use **/
  __IOM uint32_t INSENSE;        /**< Input Sense Register  */
  __IOM uint32_t LOCK;           /**< Configuration Lock Register  */
} GPIO_TypeDef;                  /** @} */

/**************************************************************************//**
 * @addtogroup EFR32BG13P_GPIO
 * @{
 * @defgroup EFR32BG13P_GPIO_BitFields  GPIO Bit Fields
 * @{
 *****************************************************************************/
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

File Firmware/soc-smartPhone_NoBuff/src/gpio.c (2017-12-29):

/***********************************************************************************************//**
* File Name        : gpio.c
* File Description : This file contains the function to set the GPIO pin connected to LED0, which is
*                    used for the Energy Modes assignment.
* Compiler         : arm-none-eabi-gcc
* Linker           : arm-none-eabi-ld
* Debugger         : arm-none-eabi-gdb
*************************************************************************************************/
#include "gpio.h"
//#include "main.h"
#include "em_gpio.h"
#include "bma280.h"
//#include "i2c.h"
#include "em_core.h"
#include "graphics.h"
#include "stdint.h"


//added shekhar
#include <stdint.h>
#include <stdio.h>
#include <stdbool.h>

/* BG stack headers */
#include "bg_types.h"
#include "gatt_db.h"
#include "native_gecko.h"
#include "infrastructure.h"

/* application specific headers */
#include "app_hw.h"
#include "app_ui.h"
#include "app_timer.h"

/* Own header*/
#include "htm.h"
//end shekhar

/* Define single and double tap values */
#define SINGLETAP 0x20
#define DOUBLETAP 0x10

#define PMU_RANGE_Reg 0x0F
#define PMU_BW_Reg 0x10
#define PMU_RANGE_Val 0x05
#define PMU_BW_Val 0x0C
#define PMU_RANGE_Val1 0x03 //shekhar change to 2g
#define PMU_BW_Val1 0x0F // shekhar change to 2KHz

int switch_on = 0;
volatile int16_t xtempValue = 0;
volatile int16_t ytempValue = 0;
volatile int16_t ztempValue = 0;
volatile int16_t bma280_temp =0;
int16_t Xdata_FIFO;
int16_t Ydata_FIFO;
int16_t Zdata_FIFO;
static uint8_t fifo_index;
//bool i2c_flag = false;
/**************************************************************************//**
 * @brief	Initialize GPIO pins
 * @param	None
 * @return	None
 *****************************************************************************/
void gpio_init(void){

//	GPIO_DriveStrengthSet(LED0_port, gpioDriveStrengthStrongAlternateStrong);
//	GPIO_PinModeSet(LED0_port, LED0_pin, gpioModePushPull, LED0_default);
//
//	GPIO_DriveStrengthSet(LED1_port, gpioDriveStrengthStrongAlternateStrong);
//	GPIO_PinModeSet(LED1_port, LED1_pin, gpioModePushPull, LED1_default);
//
//	GPIO_PinModeSet(ADC_port, ADC_pin, gpioModeDisabled, ADC_default);

	/*Over voltage disable for analog pin PortA pin 0*/
	//GPIO->P[gpioPortA].OVTDIS = 0x0001;

	GPIO_PinModeSet(SPI_CS_port, SPI_CS_pin, gpioModePushPull, SPI_CS_default);
	GPIO_PinModeSet(SPI_SCLK_port, SPI_SCLK_pin, gpioModePushPull, SPI_SCLK_default);
	GPIO_PinModeSet(SPI_MOSI_port, SPI_MOSI_pin, gpioModePushPull, SPI_MOSI_default);
	GPIO_PinModeSet(SPI_MISO_port, SPI_MISO_pin, gpioModeInput, SPI_MISO_default);

//	GPIO_PinModeSet(I2C_SCL_port, I2C_SCL_pin, gpioModeWiredAnd, I2C_SCL_default);
//	GPIO_PinModeSet(I2C_SDA_port, I2C_SDA_pin, gpioModeWiredAnd, I2C_SDA_default);
//	GPIO_PinModeSet(I2C_Bus_port, I2C_Bus_pin, gpioModePushPull, I2C_Bus_default);
}
/**************************************************************************//**
 * @brief	Initialize GPIO interrupt
 * @param	None
 * @return	None
 *****************************************************************************/
void gpio_interrupt_int(void)
{
	GPIO_IntClear(GPIO_IntGet());
	GPIO_PinModeSet(GPIO_INTERRUPT_port, GPIO_INTERRUPT_pin, gpioModeInput, GPIO_INTERRUPT_default);
	GPIO_IntConfig(GPIO_INTERRUPT_port, GPIO_INTERRUPT_pin, true, false, false);
	GPIO_IntEnable(GPIO_INT_ENABLE);
	//NVIC_SetPriority(GPIO_ODD_IRQn, 3);
	NVIC_EnableIRQ(GPIO_ODD_IRQn);
}
/**************************************************************************//**
 * @brief	GPIO Interrupt Handler
 * @param	None
 * @return	None
 *****************************************************************************/
void GPIO_ODD_IRQHandler(void)
{
	CORE_ATOMIC_IRQ_DISABLE();
		//GPIO_PinOutClear(SPI_CS_port, SPI_CS_pin);
		//GPIO_PinModeSet(SPI_CS_port, SPI_CS_pin, gpioModePushPull, 0);
		BMA280_RegisterRead(USART1,0x16);
		BMA280_RegisterRead(USART1,0x16);
		//GPIO_PinOutClear(SPI_CS_port, SPI_CS_pin);
		BMA280_RegisterRead(USART1,0x21);

		bool flag = false;
		uint8_t rxdata = BMA280_RegisterRead(USART1,INT_STATUS_0);
		if((switch_on== 0) & (rxdata == 0x10))
		{
			//BMA280_RegisterWrite(USART1,0x16,0x20);
			//BMA280_RegisterWrite(USART1,0x19,0x20);

			GPIO_PinOutSet(LED0_port, LED0_pin);	//if yes, set LED 0
			switch_on++;
			/* BMA280_TEMP- SHEKHAR*/
						uint8_t temp_complement = BMA280_RegisterRead(USART1,0x08);
					    uint8_t sign = (temp_complement >> 7);
					    uint8_t temp = ~(temp_complement);
					    temp = temp + 1;
					    bma280_temp = (23 - temp);

					    xtempValue = 0;
					    ytempValue = 0;
					    ztempValue = 0;
					    BMA280_RegisterWrite(USART1,0x16,0x50);
					    			BMA280_RegisterWrite(USART1,0x19,0x50);

					    			GPIO_PinOutSet(LED0_port, LED0_pin);	//if yes, set LED 0

					    			BMA280_RegisterWrite(USART1,PMU_RANGE_Reg,PMU_RANGE_Val);
					    			BMA280_RegisterWrite(USART1,PMU_BW_Reg,PMU_BW_Val);

					    htmTemperatureMeasure();
			/* BMA280_TEMP- SHEKHAR*/

		}
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
